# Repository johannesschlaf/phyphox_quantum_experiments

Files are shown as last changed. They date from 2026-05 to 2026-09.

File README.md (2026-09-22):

# Quantum experiments with phyphox
Language: **English** | [Deutsch](./README.de.md)

In this repository there are all the files needed for the ready-made phyphox-based quantum experiments.
 - **English instructions regarding the conduction of the experiments are now ready and available.**
 - **English instructions regarding the manufacturing of the DIY setup for measuring Planck's constant are currently in the works. They will be available in the future.**

## Measuring Planck's constant
In this experiment, the threshold voltages of LEDs with different peak wavelengths $\lambda$ are measured. From these, the respective photon energy can be calculated and plotted over $\nu=\frac{c}{\lambda}$. Planck's constant equals the slope of the line of best fit through these data pairs.<br>
This experiments needs a DIY setup that needs to be manufactured. Important manufacturing techniques include 3D printing, through-hole soldering of electronic components on a board, as well as sealing-in threaded inserts. In the folder _Instructions_ you will find a detailed construction manual.

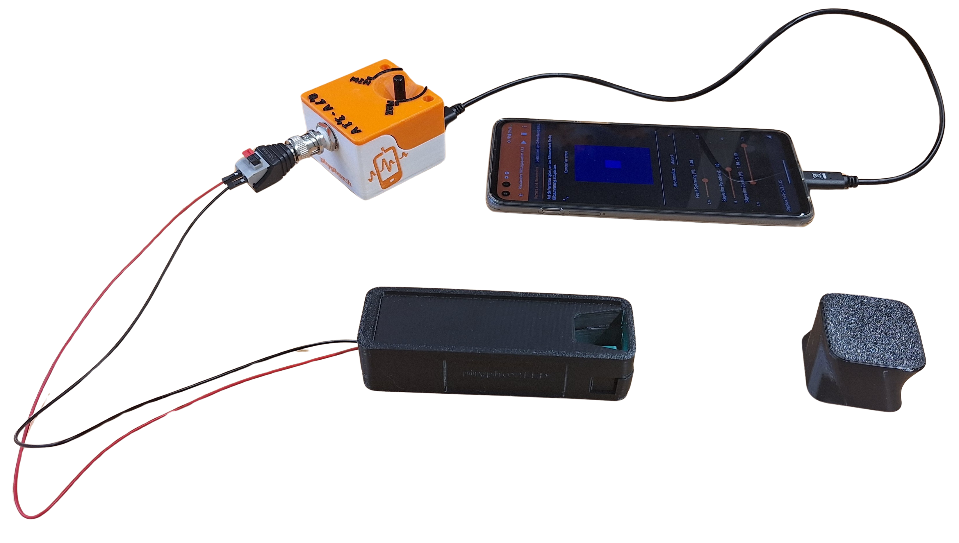
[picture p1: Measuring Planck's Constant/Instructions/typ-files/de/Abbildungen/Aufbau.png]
Picture of DIY setup
 

## BB84 analogy
The BB84 protocol is a procedure used in quantum cryptography, in which single photons in specific polarisation states are sent and measured in a specific way in order to securely generate and transmit keys simultaneously. Further information can be found in the guide in the folder _Instructions_.<br>
The basic experiment requires just two smartphones, the simulation fo an eavesdropping attempt requires three smartphones.

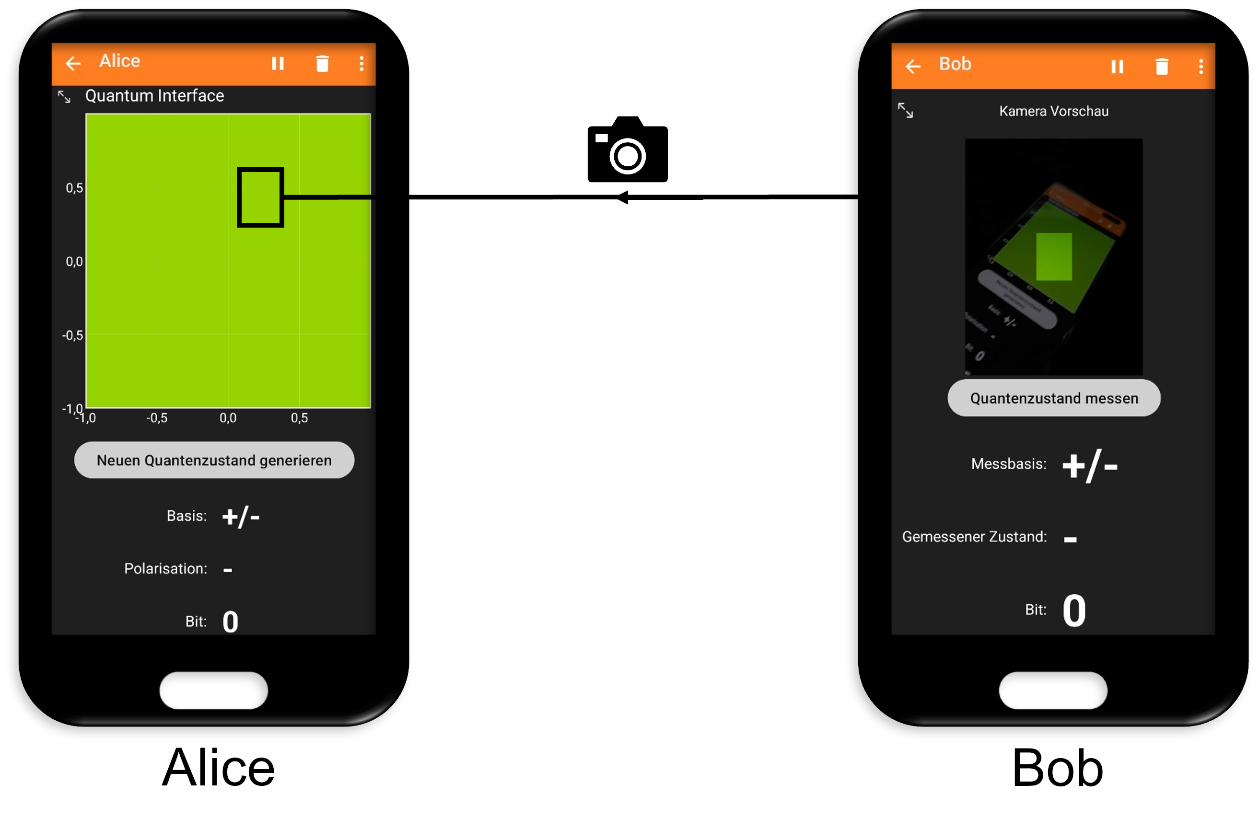
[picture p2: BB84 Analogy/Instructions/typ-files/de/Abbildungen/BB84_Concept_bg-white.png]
BB84 Concept Diagram


## Quantized conductance
...coming soon...

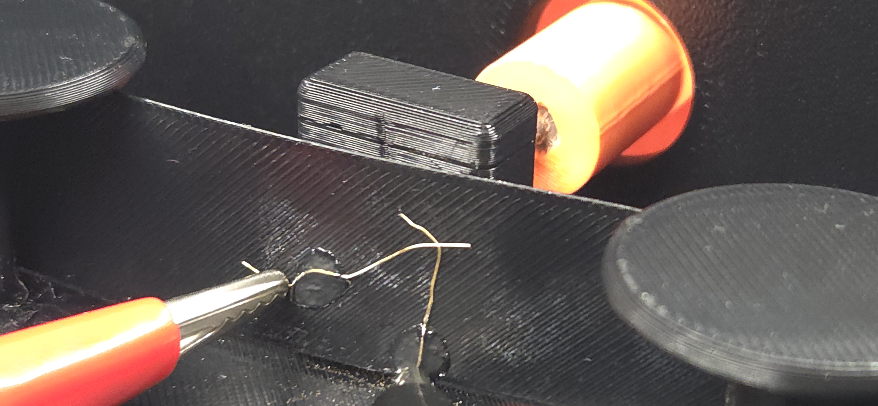
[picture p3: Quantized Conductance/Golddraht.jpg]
Picture of experimental setup


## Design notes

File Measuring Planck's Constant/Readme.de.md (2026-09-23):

# Bestimmung des Planck'schen Wirkungsquantums
Sprache: [English](./README.md) | **Deutsch**

In diesem Experiment werden die Schwellenspannungen von LEDs unterschiedlicher Peak-Wellenlängen $\lambda$ bestimmt. Aus diesen wiederum kann die zugehörige Photonenenergie berechnet und über $\nu=\frac{c}{\lambda}$ aufgetragen werden. Das Planck'sche Wirkungsquantum wird als Steigung der Ausgleichsgerade durch die aufgetragenen Punkte bestimmt.<br>
Für dieses Experiment muss ein DIY-Aufbau gefertigt werden. Wesentliche Fertigungsschritte sind 3D-Druck von Bauteilen, Durchstecklöten elektronischer Komponenten auf einer Platine sowie das Einschmelzen von Gewindeeinsätzen. 
Eine detaillierte Bauanleitung sowie eine Anleitung zur Durchführung finden sich im Ordner _Instructions_.

<br><br>
<i>
Vielen Dank an:
- Pierre Kellermann für das Konzipieren eines Prototypen der Abdunklungsbox sowie für die Stabilisierungshilfe.
- Marius Rieck für das Konzipieren eines DIY-Workshops für Schüler:innen sowie das Bereitsstellen der entsprechenden Präsentationsfolien.
</i>

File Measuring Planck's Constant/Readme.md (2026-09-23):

# Measuring Planck's Constant
Language: **English** | [Deutsch](./README.de.md)

In this experiment, the threshold voltages of LEDs with different peak wavelengths $\lambda$ are measured. From these, the respective photon energy can be calculated and plotted over $\nu=\frac{c}{\lambda}$. Planck's constant equals the slope of the line of best fit through these data pairs.<br>
This experiment needs a DIY setup that needs to be manufactured. Important manufacturing techniques include 3D printing, through-hole soldering of electronic components on a board, as well as sealing-in threaded inserts. In the folder _Instructions_ you will find a detailed construction manual.

<br><br>
<i>
Thanks to:
- Pierre Kellermann for designing a prototype for the blackout box as well as the stabilisation aid.
- Marius Rieck for creating and testing a DIY workshop concept for pupils and providing the respective presentation slides.
</i>

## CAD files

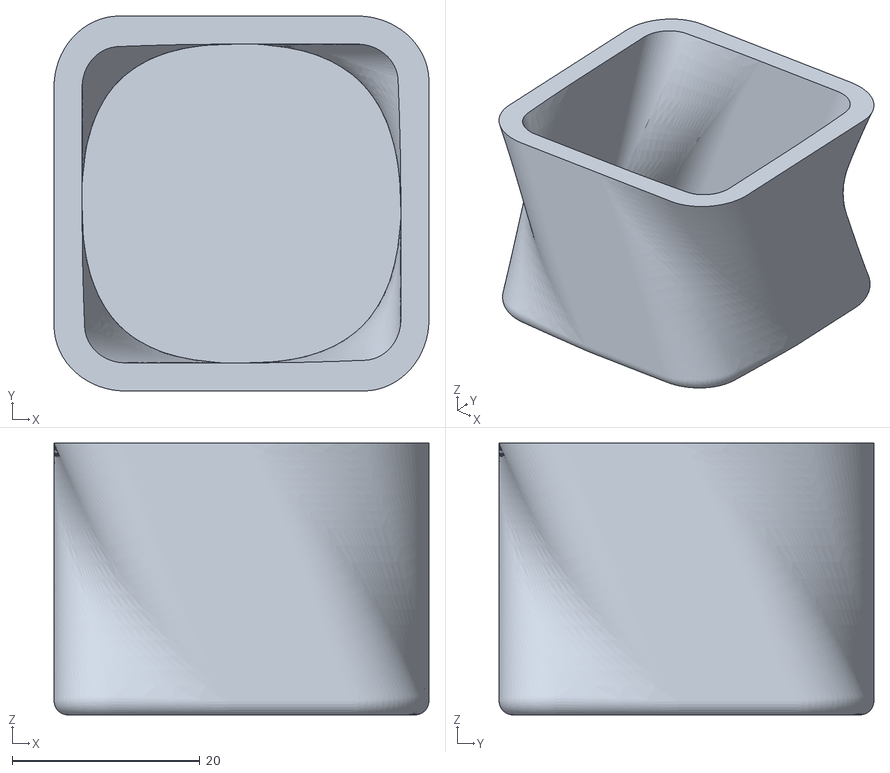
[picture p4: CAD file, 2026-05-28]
Measuring Planck's Constant/Printing files/Stabilisation_Aid_PBK.stl
40.0 x 40.0 x 29.0

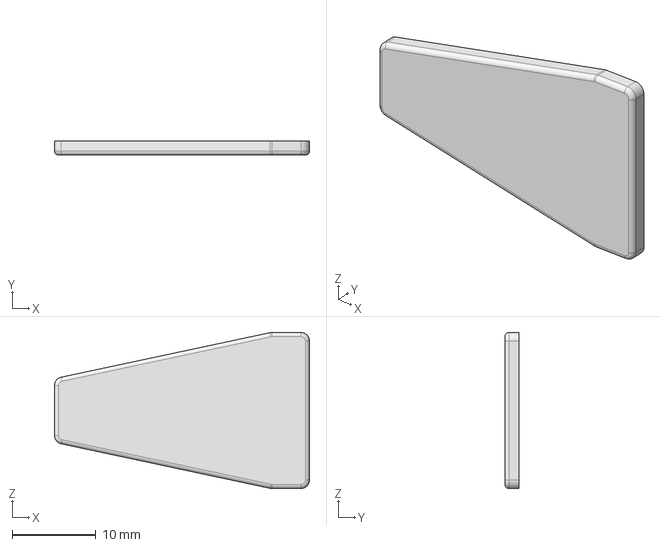
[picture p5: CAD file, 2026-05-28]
Measuring Planck's Constant/Printing files/phyphox_LED_Reflective_Insert_V3.1E.stp
30.4 x 1.70 x 18.6 mm

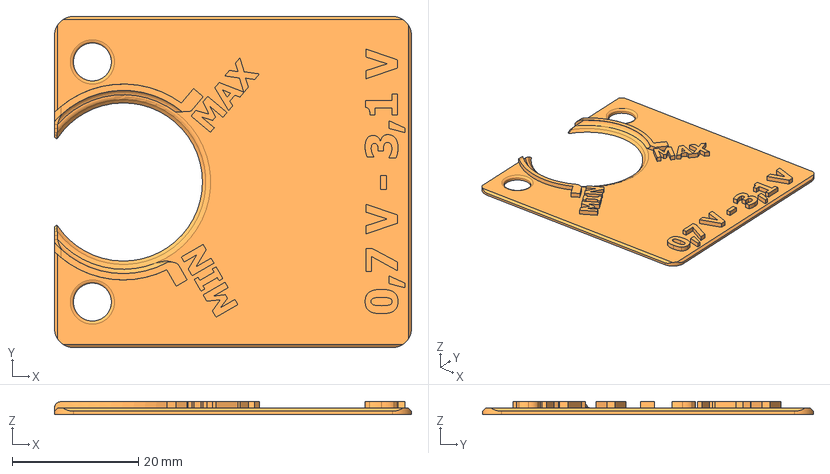
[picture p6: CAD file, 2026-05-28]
Measuring Planck's Constant/Printing files/phyphox_h_Scale_V4.2.stp
56.5 x 52.4 x 2.00 mm

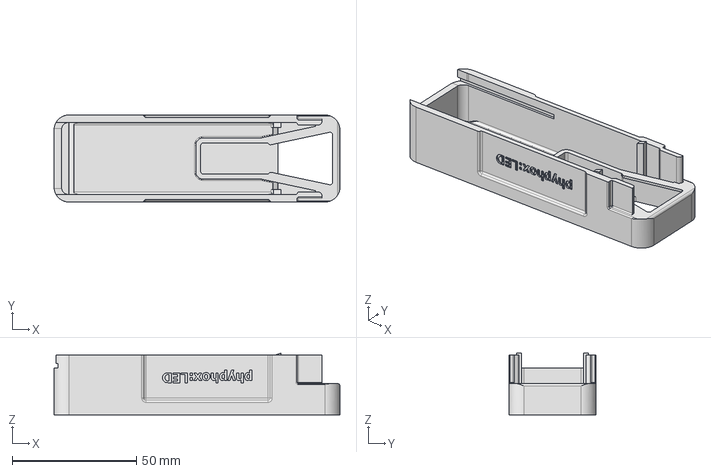
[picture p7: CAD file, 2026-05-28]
Measuring Planck's Constant/Printing files/phyphox_LED_Top_V3.5.4.stp
115.0 x 35.0 x 24.8 mm

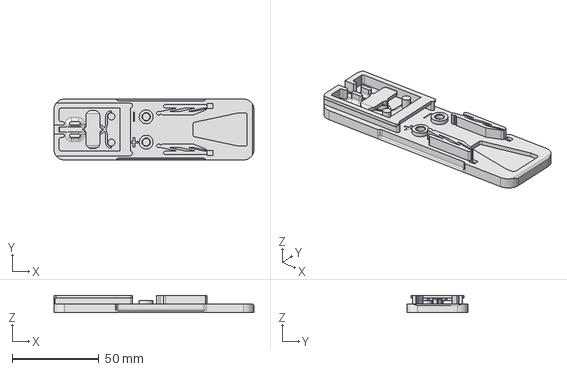
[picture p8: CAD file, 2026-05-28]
Measuring Planck's Constant/Printing files/phyphox_LED_Bottom_V3.5.3.stp
115.0 x 35.0 x 10.0 mm

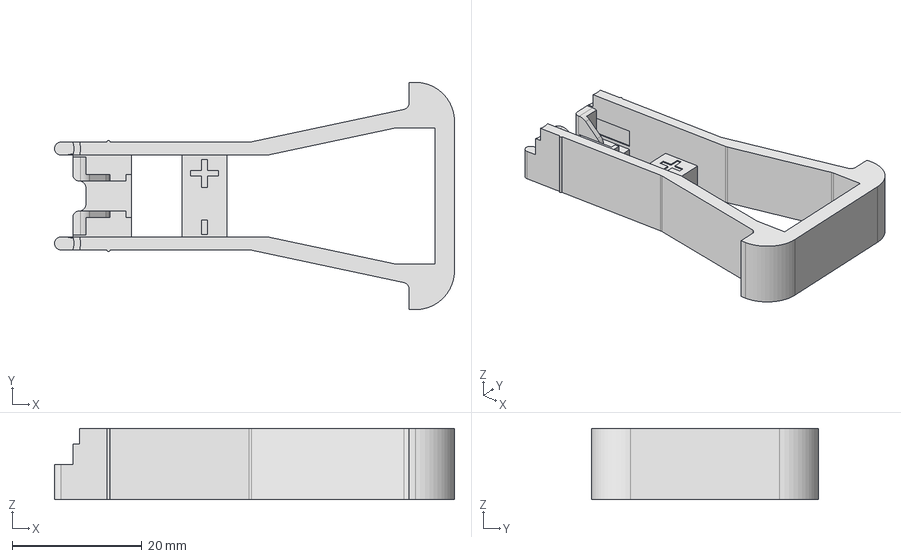
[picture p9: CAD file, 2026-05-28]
Measuring Planck's Constant/Printing files/phyphox_LED_Inset_V3.3.stp
61.6 x 35.0 x 11.0 mm

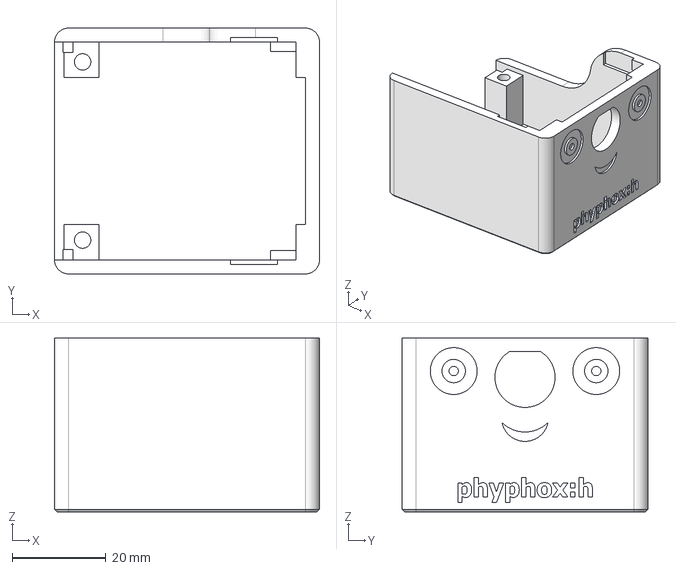
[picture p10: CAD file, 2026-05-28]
Measuring Planck's Constant/Printing files/phyphox_h_Bottom_V4.2.3.stp
56.5 x 52.4 x 37.0 mm

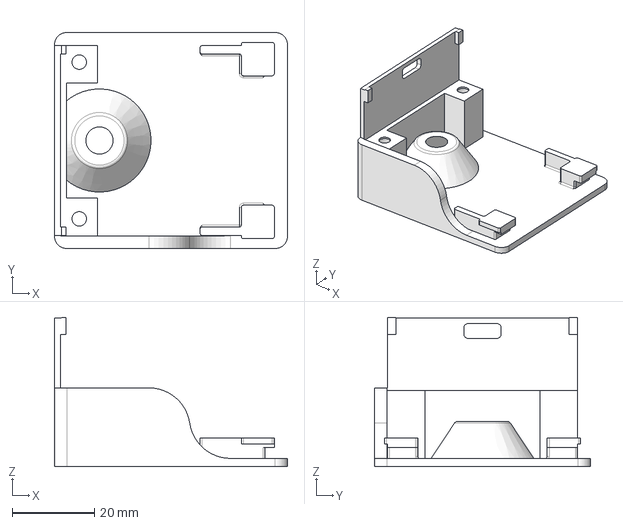
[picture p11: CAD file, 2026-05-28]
Measuring Planck's Constant/Printing files/phyphox_h_Top_V4.2.1.stp
56.5 x 52.4 x 36.2 mm

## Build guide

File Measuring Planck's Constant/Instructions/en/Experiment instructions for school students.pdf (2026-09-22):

®

# Planck’s Constant

## Material

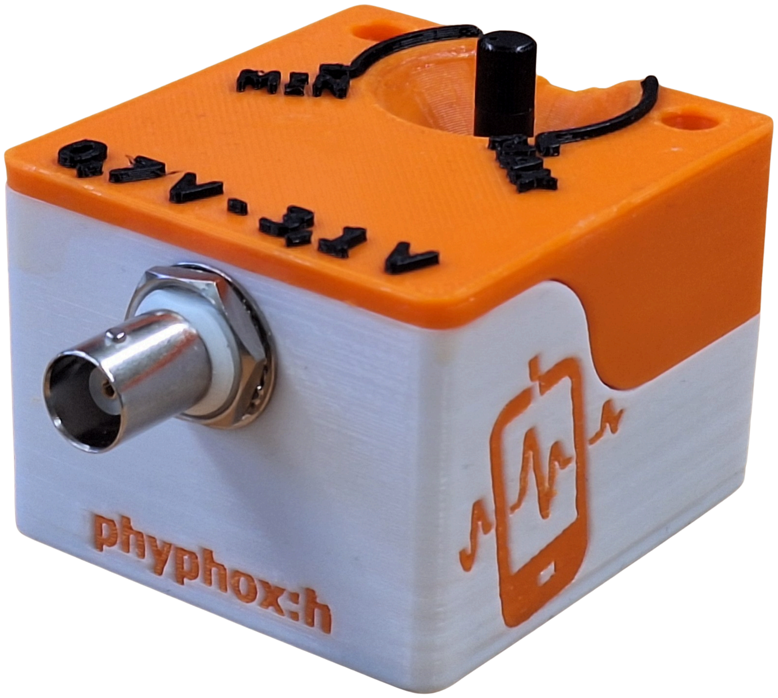
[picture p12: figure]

phyphox:h-box (voltage
control)

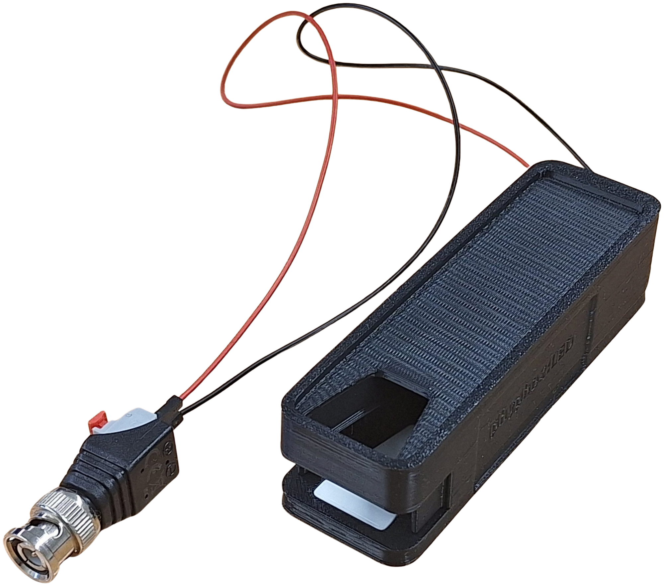
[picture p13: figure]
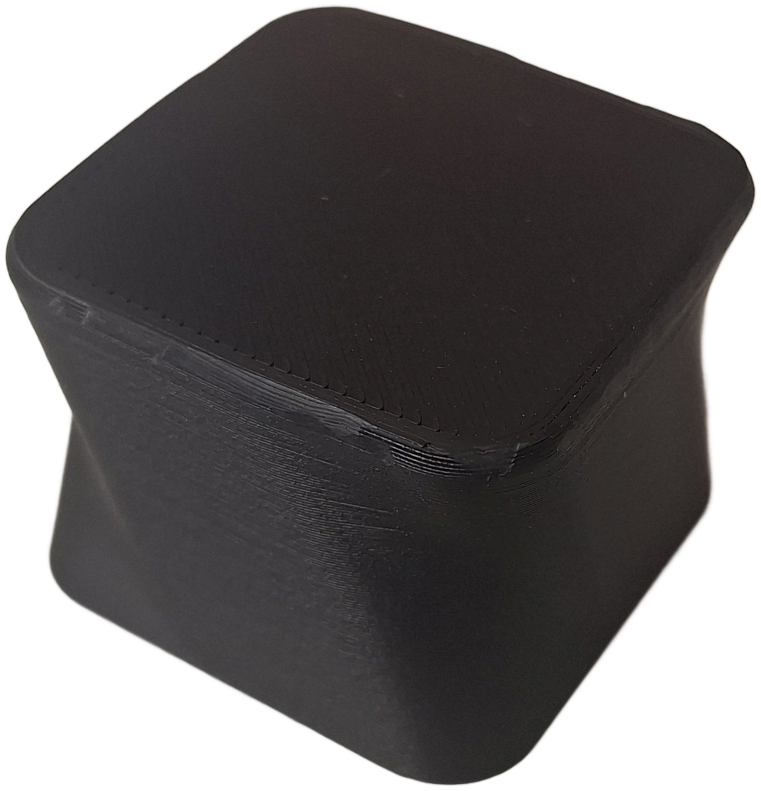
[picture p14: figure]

Blackout box | Stabilisation aid

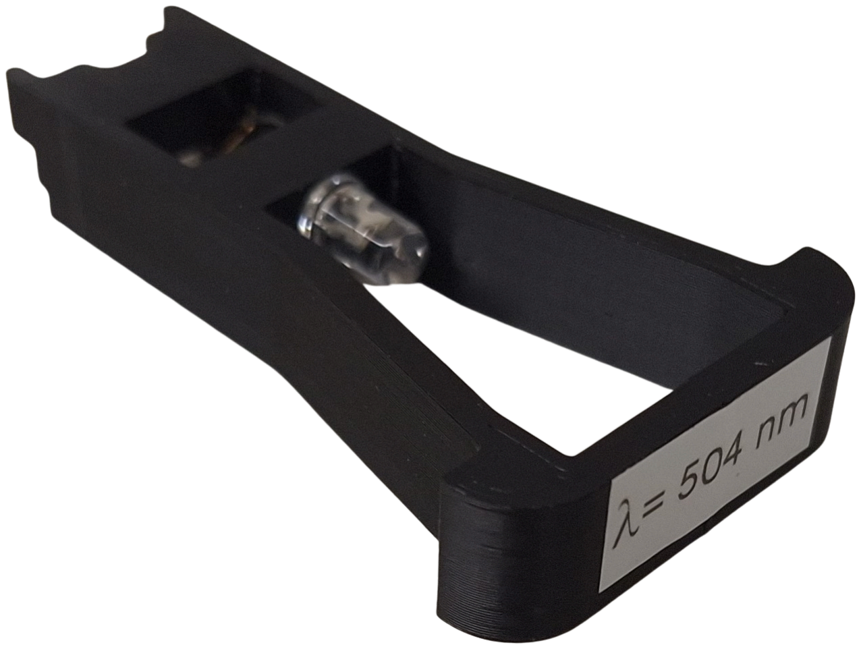
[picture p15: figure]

Various LED inserts of different wavelengths

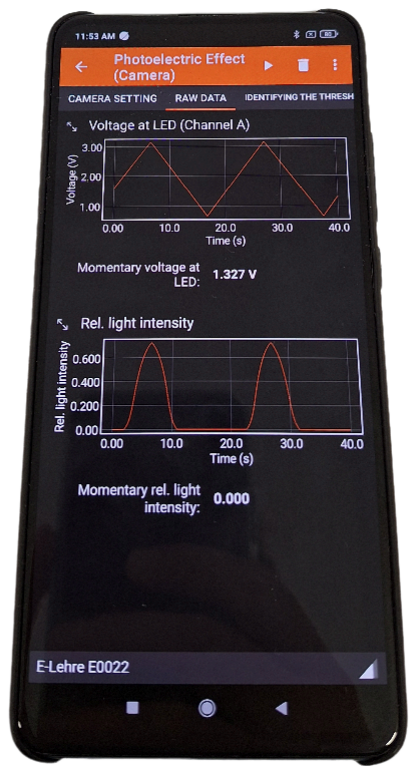
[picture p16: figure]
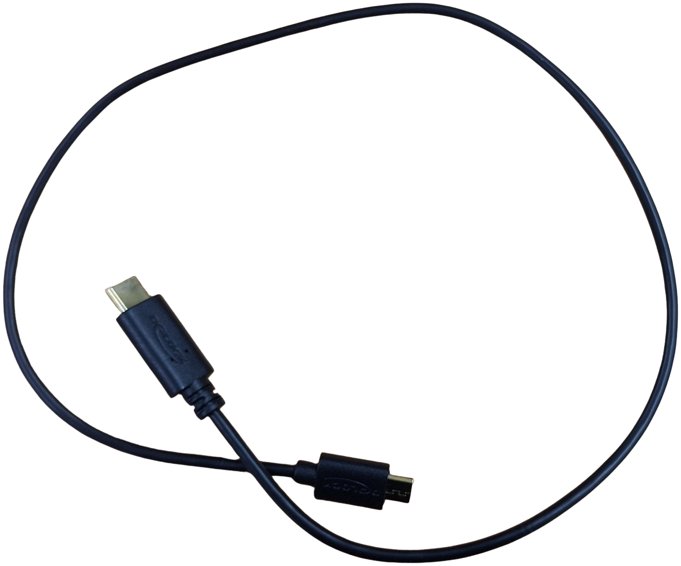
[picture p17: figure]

Connection cable | Smartphone (light intensity measurement)

This document is licensed under CC BY 4.0. https://creativecommons.org/licenses/by/4.0/. Author: Johannes Schlaf

## Setup/Preparation

1. Set up the experimental apparatus according to the figure below.
2. Download the corresponding phyphox experiment bundle:
- The phyphox: h-Box must be connected to the smartphone (or another power source).
- Open the phyphox app.
- Click on the plus symbol.
- Select „Add experiment for Bluetooth device“.
- Select your phyphox:h-Box from the list (numbering on the side).
- Wait until the download is complete.
- Save the desired experiment (or both) in the collection.

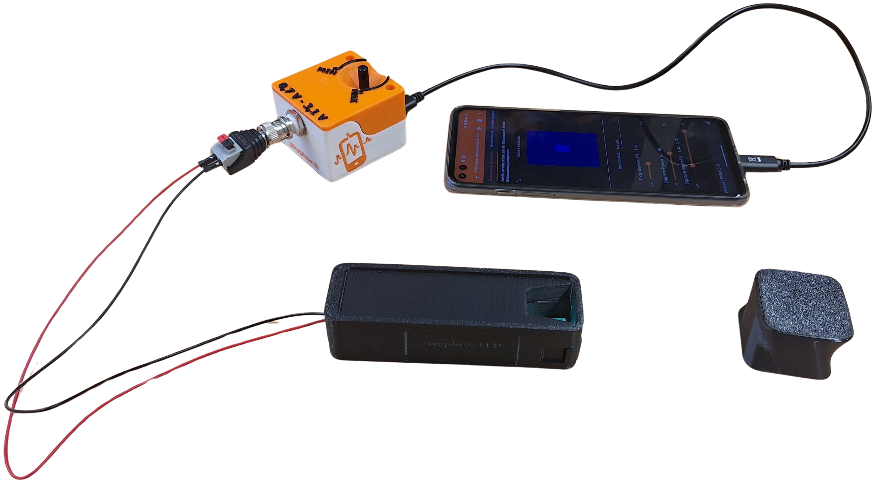
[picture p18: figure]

Completed setup

## Procedure with the smartphone camera

- If the appropriate phyphox experiment does not open automatically or needs to be reopened during the experiment:
1. Select the phyphox experiment Planck’s Constant (camera in the icon) under the Quantum Physics section.
2. Select your phyphox: h-Box from the appearing list of Bluetooth devices (the number is on the side of the box). ⇒ The box will now connect to the app and send the value of the applied voltage.
- Determine the threshold voltages of several LEDs (13 steps):
1. Insert an LED insert into the blackout box.
2. Set the voltage regulator on the phyphox: h-Box to maximum.
3. Place your smartphone on the blackout box so that the camera is positioned above the white reflective material. Use the stabilization aid if necessary.
4. Reduce the voltage to the highest value at which the camera’s selection area has no overexposure anywhere (i.e. the selection area must not contain any redmarked areas).
- The selection area is the slightly brighter rectangle within the camera preview.
- Overexposure may occur outside the selection area.
- The selection area can be moved. To do this, tap on the camera preview.
5. Switch to the „Identify the threshold voltage“ tab.
6. Start the measurement (play button in the top right).
7. Record an LED characteristic curve by slowly reducing the voltage.
8. Pause the measurement.
9. Place the green regression line in the characteristic curve by adjusting the minimum and maximum considered intensity. The regression line should run through the approximately linear region of the characteristic curve. Any saturation curve should therefore not be taken into account.
10. Note down the threshold voltage Uthreshold calculated by the experiment in the table on page 7. Also note the corresponding uncertainty.

11. Enter the wavelength of the LED in the experiment and save the wavelengththreshold voltage pair in the experiment. The pair is now available in the „Measuring h“ tab.
12. Do not use the button with the trash can symbol during the procedure. This deletes all data.
Now delete the measurement curve using the button provided specifically for this purpose.
13. Repeat the measurement process with the next LED.

## Procedure without the smartphone camera

- If the appropriate phyphox experiment does not open automatically or needs to be reopened during the experiment:
1. Select the phyphox experiment Planck’s Constant (no camera in the icon) under the Quantum Physics section.
2. Select your phyphox: h-Box from the appearing list of Bluetooth devices (the number is on the side of the box). ⇒ The box will now connect to the app and send the value of the applied voltage.
- Determine the threshold voltages of several LEDs (11 steps):
1. Set the voltage regulator on the phyphox: h-Box to minimum.
2. Insert an LED insert into the blackout box.
3. Switch to the „Determine Threshold Voltage“ tab.
4. Start the measurement (play button in the top right).
5. Record an LED characteristic curve by varying the voltage.
6. Pause the measurement.
7. Place the green regression line in the characteristic curve by adjusting the minimum and maximum considered current. The regression line should run through the approximately linear region of the characteristic curve. Any saturation curve should therefore not be taken into account.
8. Note down the threshold voltage Uthreshold calculated by the experiment in the table on page 7. Also note the corresponding uncertainty.
9. Enter the wavelength of the LED in the experiment and save the wavelengththreshold voltage pair in the experiment. The pair is now available in the „Measuring h“ tab.
10. Do not use the button with the trash can symbol during the procedure. This deletes all data.
Now delete the measurement curve using the button provided specifically for this purpose.
11. Repeat the measurement process with the next LED.

## Analysis

1. Calculate the corresponding photon energies from the threshold voltages

Reminder: e = 1.602 ⋅ 10

−19 C

1. Enter the obtained frequency-energy pairs into the diagram on page 8.
2. Draw a regression line in the diagram and determine its gradient.
3. If uncertainties were addressed:
- Draw the lines of minimum and maximum slope (within the scope of the uncertainties) in the diagram.
- Calculate the uncertainty in the measured value for Planck’s constant.
4. Compare the obtained value for Planck’s constant with the value displayed in the app and discuss possible deviations.

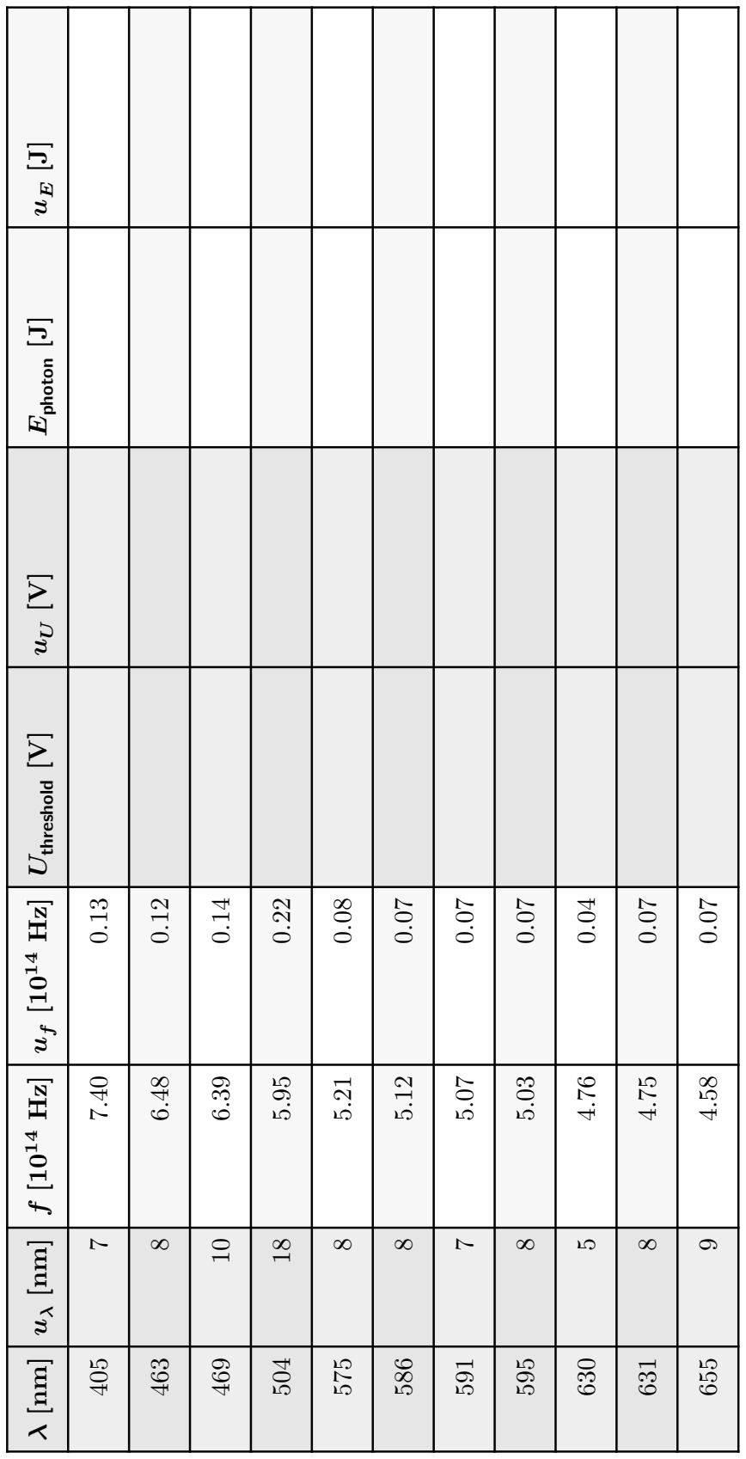
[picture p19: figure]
Uthreshold [V]; Ephoton [J]

Table 1: Measurement data of threshold voltage as a function of wavelength.

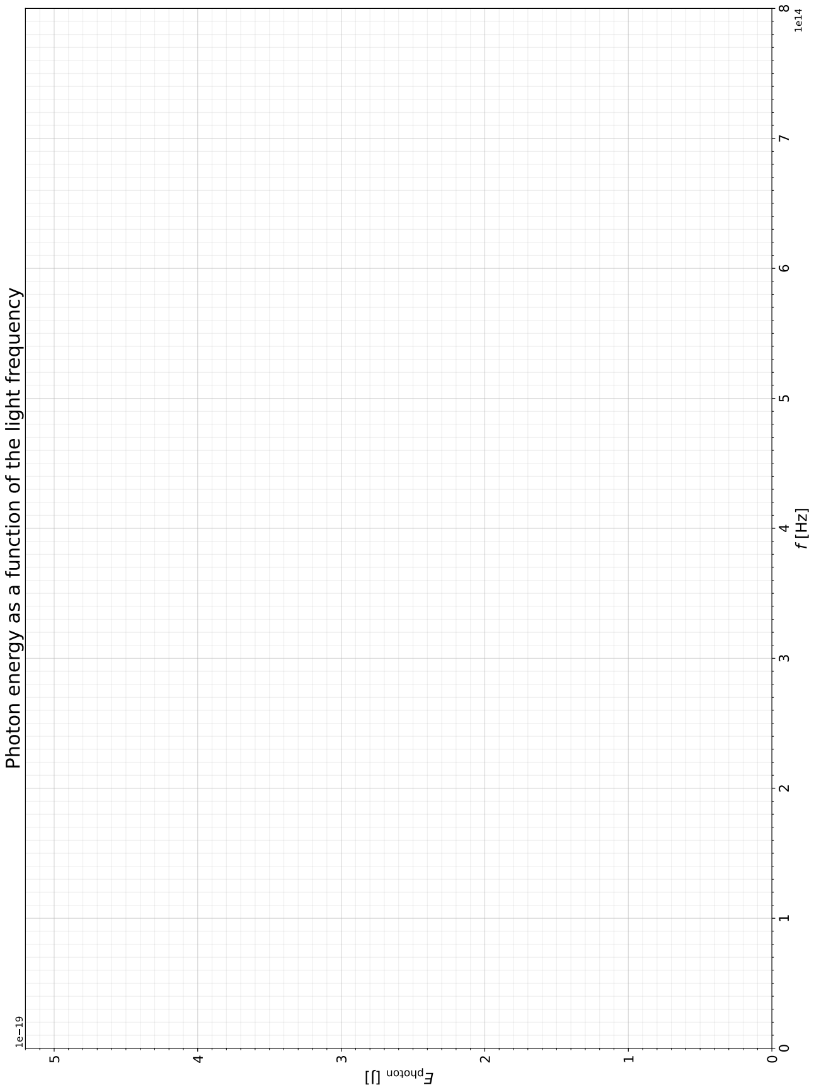
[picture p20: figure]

## 1e 19 Photon energy as a function of the light frequency



## 1e 19 Photon energy as a function of the light frequency

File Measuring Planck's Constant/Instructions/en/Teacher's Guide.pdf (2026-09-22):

®

# Planck’s Constant

## – Teacher’s Guide –

## 1 Motivation and Objective

This experiment serves to address the quantization of the energy of electromagnetic radiation, the discovery of which initiated a series of rapidly successive research studies and quantummechanical models through which numerous previously unexplained phenomena, such as emission and absorption spectra, could be explained (the introduction of Planck’s constant as a free parameter in a derivation of the black-body radiation spectrum in 1900 by Max Planck is therefore generally regarded as the birth of quantum physics, even though its interpretation as quantization of the energy of electromagnetic radiation was made later in 1905 by Albert Einstein). This is done by determining Planck’s constant from the threshold voltage of different LEDs.

## 2 Physical Foundations

### 2.1 Light

Light as an electromagnetic wave
In general, a wave is understood as a temporal change of a state that propagates through space, whereby no matter is transported but energy is. The state of an electromagnetic field is described by the electric field strength E⃗ and the magnetic induction B⃗. In an electromagnetic wave, E⃗ and B⃗ are oriented perpendicular to each other. The wave propagates in a direction that is perpendicular to the plane formed by E⃗ and B⃗. E⃗ and B⃗ change periodically (see

Figure 1).
The distance over which E⃗ and B⃗ complete one period is called the wavelength λ. It is related

to the period T and the oscillation frequency f as follows:

f =

1
T

=

c
λ

Here, c corresponds to the speed of light in vacuum (c ≈ 299,800,000 m
s

).
The perceived color of light depends on its wavelength (see Figure 2).

This document is licensed under CC BY 4.0. https://creativecommons.org/licenses/by/4.0/. Author: Johannes Schlaf

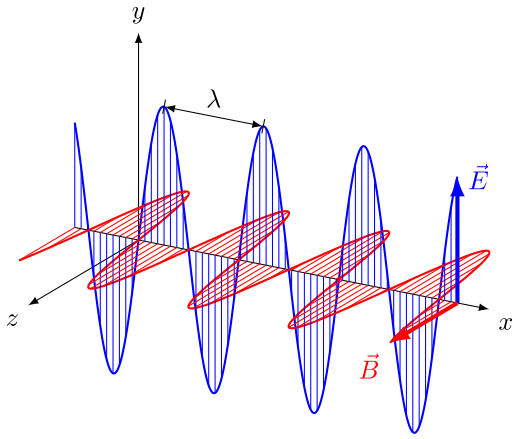
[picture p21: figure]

Figure 1: Light as an electromagnetic wave. The wavelength λ corresponds to the distance between two points of maximum electric field strength. Image source: Wikimedia Commons. By: And1mu.

Light as particles
Light energy is quantized, i.e. it exists only as multiples of the smallest possible energy units, so-called photons. The energy Eph of a photon depends on the frequency f. The following holds:

Eph = ℎ ⋅ f

The proportionality constant ℎ is called Planck’s constant. It is a fundamental physical constant.

The division of light energy into photons corresponds to the idea of very tiny light particles. It contradicts the idea of light as a continuous electromagnetic wave. Depending on the experiment, light behaves like a collection of light particles, like an electromagnetic wave, or like both simultaneously. This fact is referred to as wave-particle duality.

Figure 2: Color spectrum of visible light as a function of wavelength. Image source: Schmidt,
P. & Windhausen, S. (2024). Lohmeyer Praktische Bauphysik, p. 806. Springer Vieweg.

### 2.2 Diodes

Diodes are electronic components that conduct current only in one direction. If they are connected the wrong way round (reverse direction), they block the circuit and can be damaged if the voltage is high enough. If they are connected in the forward direction, a certain voltage, the so-called threshold voltage, must be reached before current can flow. For conventional diodes, this voltage is typically around 0.7 V. A typical current-voltage characteristic can be found in Figure 3.
The threshold voltage can be approximately determined by drawing a tangent to the characteristic curve. The threshold voltage corresponds approximately to the zero crossing of the tangent.

For so-called LEDs (Light Emitting Diodes), part of the electrical energy is converted into photons. The minimum threshold voltage Uthreshold required for the LED to emit light corresponds to the photon energy. The following holds:

EPh = e ⋅ Uthreshold

Here, e corresponds to the elementary charge (e ≈ 1.602 ⋅ 10

−19 C).

pagebreak()

## 3 Experimental Setup and Procedure

Data acquisition in this experiment is carried out with the smartphone app phyphox, developed at RWTH Aachen University. This app accesses the internal sensors of the smart-

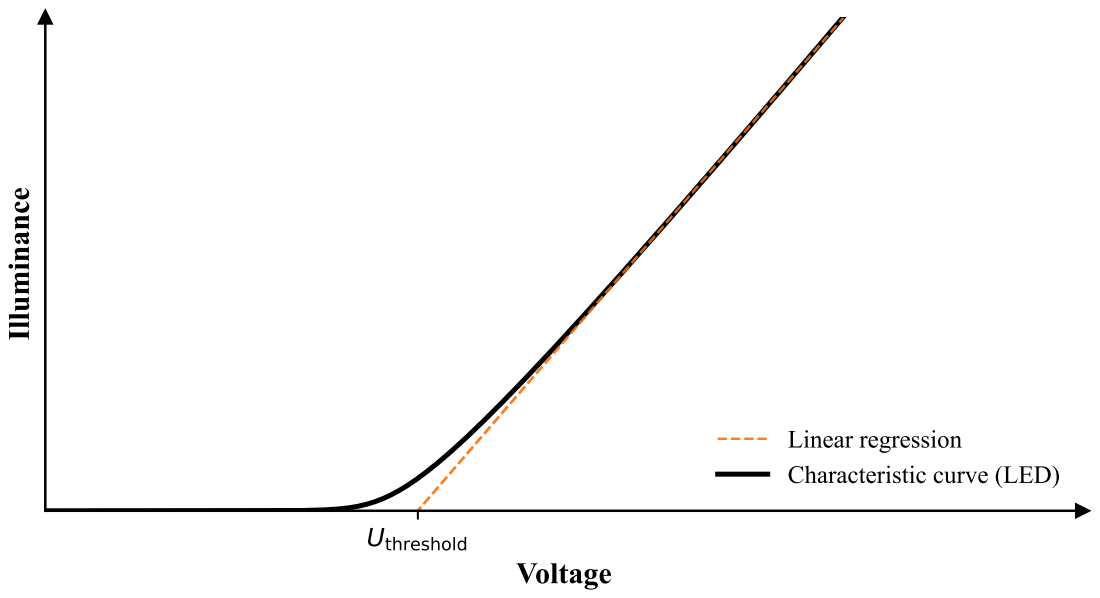
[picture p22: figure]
Uthreshold; Voltage; Illuminance; Linear regression Characteristic curve (LED)

Figure 3: Typical current–voltage characteristic of a diode with a series resistor.

phone and can thus read out measured quantities such as, for example, the instantaneous acceleration. In addition, external sensors can be integrated via Bluetooth. In phyphox, you choose what to measure by selecting one of the available experiments. New experiments can be added over Bluetooth from an external sensor device or through a QR code.

To determine the threshold voltage of an LED, a characteristic curve as in Figure 3 is required. The current through the LED is approximately proportional to its luminous intensity, so instead of measuring the current directly, you can measure the illuminance inside a blackout box. With the DIY setup provided for this experiment, both current measurement and measurement of the illuminance via the smartphone camera are possible.

Further information regarding setup, procedure, and evaluation can be found in the experiment instructions.

## 4 Background Information

- In a simplified picture, a diode consists of an n-doped semiconductor (with free electrons in the crystal lattice) and a p-doped semiconductor (with electron deficiencies / free holes) joined together. At the contact point (the so-called pn junction), a charge zone without free charge carriers forms due to the diffusion of electrons (concentration equalization) from n to p; this is the so-called depletion region. If a diode is connected with the positive terminal to n and the negative terminal to p, electrons flow from n to the positive terminal and from the negative terminal to p, which enlarges the charge zone and thus the depletion region. In this direction, only a minimal current flow in the range of a few microamperes occurs (so-called reverse current). If the LED is connected the other way round, the depletion region becomes smaller until, above a certain voltage (threshold or turn-on voltage, about 0.7 V for an ordinary diode, between 1.6 V and 3.3 V for LEDs with a visible emission spectrum), it disappears and current can flow. Photon generation occurs during the recombination of electrons (n) with holes (p), which are located at different energy levels.

Uthreshold
Voltage

Illuminance

Figure 4: Simplified characteristic curve of an LED. Current flows only after the threshold voltage is exceeded and then increases linearly with voltage.

- The simplified explanation above corresponds to the characteristic curve in Figure 4. In reality, an ideal diode actually follows the following characteristic (see Figure 5):

I = Ireverse ⋅ exp(

e ⋅ U
n ⋅ k ⋅ T

− 1)

Here, n is the so-called ideality factor or emission coefficient. For LEDs, it is typically n = 1.4.

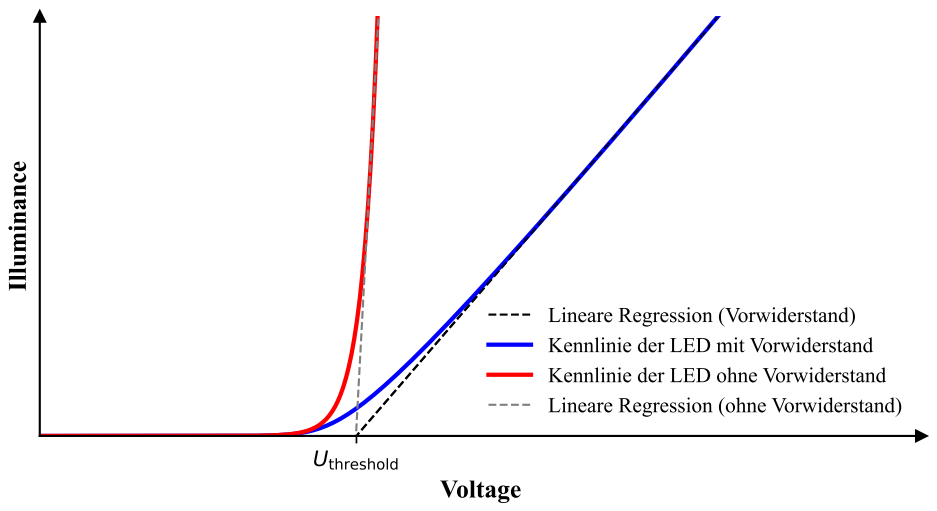
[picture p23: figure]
Uthreshold; Voltage; Illuminance; Lineare Regression (Vorwiderstand) Kennlinie der LED mit Vorwiderstand Kennlinie der LED ohne Vorwiderstand Lineare Regression (ohne Vorwiderstand)

Figure 5: Simplified characteristic curve of an LED. Current flows only after the threshold voltage is exceeded and then increases linearly with voltage.

- The threshold voltage is usually defined as the voltage at which 10 % of the maximum permissible current flows through the diode.
- Even for an ideal diode, the threshold voltage of the diode is only approximately determined by the line of best fit. This is partly because, although the characteristic curve can be approximated by a straight line locally, it follows an exponential trend overall. This is already taken into account in the phyphox experiment’s calculation of the uncertainty of the threshold voltage.
- LEDs can heat up. This leads to a change in the band structure (usually toward smaller energy differences). The LEDs should therefore not be operated for too long or with much higher voltage than necessary (operating a red LED at 3 V is generally not necessary, as the threshold voltage should be below 2 V).
- Red LEDs can have higher threshold voltages than their wavelength would suggest. This is because the energy band structure around the “light-generation zone” is often designed such that the electrons first fall to an intermediate level before recombining with the holes while emitting photons.
- If the illuminance is to be measured in the experiment:
- Overexposure of the camera must be avoided, since saturation of individual pixels (reaching the maximum brightness value in the HSV color space) in the selected area leads to distortion of the characteristic curve (see below). Therefore, the smartphone camera cannot be pointed directly at the LED, so the blackout box has a reflective surface onto which the camera should be pointed.
- The luminous intensity of an LED is only approximately proportional to the current. For higher currents, the current–luminous-intensity curve flattens, which results in a flattening of the voltage–luminous-intensity curve.
- The relative illumination values measured with the phyphox camera are not necessarily proportional to the actual illuminance everywhere.

– At higher levels, the camera often shows saturation even without overexposure, which distorts the measured curve.

– At very low illuminances, the measured values can jump abruptly.

– Some smartphone models automatically adjust the image brightness above certain light levels, so that only a scatter of points is measured.

All three effects also depend on the image processing algorithms of the respective smartphone. Turning off all switchable processing functions in the camera app can improve the measurement curves in phyphox.

- When carrying out the experiment, it is particularly important to ensure that the blackout box is sufficiently well covered and that the camera is not overexposed. Insufficient light-tightness leads to the measurement of an offset and consequently to systematically too low threshold voltages. Overexposure leads to flattening, kinks, and possibly to several approximately linear sections, which makes sensible placement of the line of best fit more difficult.

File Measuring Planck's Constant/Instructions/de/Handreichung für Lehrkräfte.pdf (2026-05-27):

®

# Das Planck’sche Wirkungsquantum

## – Handreichung für Lehrkräfte –

### 1 Motivation und Ziel

Mit diesem Versuch kann die Energiequantelung elektromagnetischer Strahlung thematisiert werden, deren Entdeckung eine Reihe schnell aufeinander folgender Forschungsarbeiten und quantenmechanischer Modelle einläutete, durch die zahlreiche vorher unverstandene Phänomene wie z.B. Emissions- und Absorptionsspektren erklärt werden konnten (die Einführung des Planck’schen Wirkungsquantums als freier Parameter in einer Herleitung zum Spektrum der Schwarzkörperstrahlung im Jahre 1900 durch Max Planck wird daher in der Regel als die Geburtsstunde der Quantenphysik bezeichnet, auch wenn dessen Deutung als Energiequantelung elektromagnetischer Strahlung erst 1905 durch Albert Einstein erfolgte). Dies erfolgt durch die Bestimmung des Wirkungsquantums aus der Schwellenspannung verschiedener LEDs.

### 2 Physikalische Grundlagen

### 2.1 Licht

Licht als elektromagnetische Welle
Unter einer Welle versteht man im Allgemeinen eine sich im Raum ausbreitende zeitliche Änderung eines Zustandes, wobei keine Materie sondern Energie transportiert wird. Der Zustand eines elektromagnetischen Feldes wird durch die elektrische Feldstärke E⃗ und die magnetische Induktion B⃗ beschrieben. Bei einer elektromagnetischen Welle sind E⃗ und B⃗ senkrecht zueinander ausgerichtet. Die Ausbreitung der Welle erfolgt in einer Richtung, die wiederum senkrecht auf der durch E⃗ und B⃗ gebildeten Ebene steht. E⃗ und B⃗ ändern sich hierbei periodisch (siehe Abbildung 1).
Die Strecke, in der E⃗ und B⃗ eine Periode durchlaufen, wird als Wellenlänge λ bezeichnet. Sie hängt mit der Periodendauer T und der Schwingungsfrequenz f wie folgt zusammen:
| f =
| 1 T = c λ

Hierbei entspricht c der Lichtgeschwindigkeit im Vakuum (c ≈ 2,988 m
| s ).
Die wahrgenommene Farbe von Licht hängt von dessen Wellenlänge ab (siehe Abbildung 2)

This document is licensed under CC BY 4.0. https://creativecommons.org/licenses/by/4.0/. Author: Johannes Schlaf

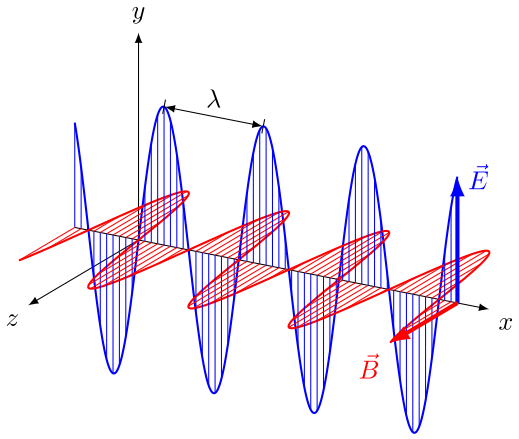
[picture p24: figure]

Abbildung 1: Licht als elektromagnetische Welle. Die Wellenlänge λ entspricht dem Abstand zweier Punkte maximaler elektrischer Feldstärke. Bildquelle: Wikimedia Commons. By: And1mu.

Licht als Teilchen
Lichtenergie ist gequantelt, d.h. sie liegt nur als Vielfaches kleinstmöglicher Energieeinheiten, sogenannter Photonen vor. Die Energie EPh eines Photons ist von der Frequenz f abhängig. Es gilt:

EPh = ℎ ⋅ f

Die Proportionalitätskonstante ℎ wird als das Planck’sche Wirkungsquantum bezeichnet. Sie ist eine fundamentale Naturkonstante.

Die Aufteilung der Lichtenergie in Photonen entspricht der Vorstellung kleinster Lichtteilchen. Sie widerspricht dem Bild von Licht als kontinuierliche elektromagnetische Welle. Je nach Experiment verhält sich Licht wie eine Ansammlung von Lichtteilchen, wie eine elektromagnetische Welle oder wie beides gleichzeitig. Diesen Sachverhalt bezeichnet man als Welle-Teilchen-Dualismus.

Abbildung 2: Farbspektrumg des sichtbaren Lichts in Abhängigkeit der Wellenlänge. Bildquelle: Schmidt, P. & Windhausen, S. (2024). Lohmeyer Praktische Bauphysik, S. 806. Springer Vieweg.

### 2.2 Dioden

Dioden sind elektronische Bauteile, welche nur in eine Richtung stromdurchlässig sind. Werden sie falsch herum angeschlossen (Sperrrichtung), sperren sie daher den Stromkreis und können, wenn die Spannung hoch genug ist, Schaden nehmen. Werden sie in Durchlassrichtung angeschlossen, muss eine gewisse Spannung, die sogenannte Schwellenspannung, erreicht werden, damit ein Strom fließen kann. Bei herkömmlichen Dioden liegt diese Spannung typischerweise bei etwa 0,7 V. Ein typische Strom-Spannungs-Kennlinie ist in Abbildung 3 zu finden.
Die Schwellenspannung kann näherungsweise bestimmt werden, indem eine Tangente an die Kennlinie angelegt wird. Die Schwellenspannung entspricht näherungsweise der Nullstelle der Tangente.

Bei sogenannten LEDs (Light Emitting Diodes) wird ein Teil der elektrischen Energie in Photonen umgesetzt. Die für das Leuchten der LED mindestens notwendige Schwellenspannung USchwelle entspricht hierbei der Photonenenergie. Es gilt:

EPh = e ⋅ USchwelle

Hierbei entspricht e der Elektronenladung (e ≈ 1,602 ⋅ 10

−19 C).

0,7 V

### Spannung

### Strom

Kennlinie der LED
Lineare Regression

Abbildung 3: Typische Strom-Spannungs-Kennlinie einer Diode mit vorgeschaltetem Widerstand.

### 3 Versuchsaufbau und Durchführung

Die Datenaufnahme erfolgt in diesem Versuch mit der an der RWTH Aachen entwickelten Smartphone-App phyphox. Diese greift auf die internen Sensoren des Smartphones zu und kann so Messgrößen wie z.B. die momentane Beschleunigung auslesen. Zudem können über Bluetooth externe Sensoren eingebunden werden. Die Auswahl, was gemessen werden soll, erfolgt über in phyphox auswählbare Experimente. Neue Experimente können über Bluetooth von einem anzusteuernden Gerät oder über einen QR-Code hinzugefügt werden.

Um die Schwellenspannung einer LED zu bestimmen, wird eine Kennlinie wie in Abbildung 3 benötigt. Der durch die LED fließende Strom ist näherungsweise proportional zu der Leuchtdichte der LED, weswegen anstelle des Stroms auch die Beleuchtungsstärke in einer Abdunklungsbox gemessen werden kann. Mit dem für dieses Experiment vorgesehenen DIY-Aufbau ist sowohl die Strommessung als auch die Messung der Beleuchtungsstärke über die Smartphone-Kamera möglich.

Weitere Informationen zu Aufbau, Durchführung und Auswertung finden Sie in der Versuchsanleitung.

### 4 Hintergrundwissen

- Eine Diode besteht (vereinfacht) aus einem n-dotierten (freie Elektronen im Kristallgitter) und einem p-dotierten (Elektronenmangen / freie Löcher) Halbleiter, die miteinander verbunden werden. Um die Kontaktstelle (den sogenannten pn-Übergang) bildet sich durch die Diffusion von Elektronen (Konzentrationsausgleich) von n zu p eine Ladungszone ohne freie Ladungsträger aus, die sogenannte Sperrschicht. Wird eine Diode mit dem Pluspol an n und dem Minuspol an p beschaltet, fließen Elektronen aus n zum Pluspol und aus dem Minuspol zu p, was die Ladungszone und somit die Sperrschicht vergrößert. In dieser Richtung kommt es nur zu einem minimalen Stromfluss im Bereich einiger Mikorampere (sogenannter Sperrstrom). Wird die LED anders herum geschaltet, verkleinert sich die Sperrschicht, bis sie ab einer bestimmten Spannung (Schwellen- oder Schleusenspannung, etwas 0,7 V für eine gewöhnliche Diode, zwischen 1,6 V und 3,3 V für LEDs mit sichtbarem Emissionsspektrum) verschwindet und ein Strom fließen kann. Die Photonenerzeugung erfolgt bei der Rekombination der Elektronen (n) mit den Löchern (p), welche sich auf unterschiedlichen Energieniveaus befinden.

0,7 V
Spannung

Strom

Abbildung 4: Vereinfachte Kennlinie einer LED. Es fließt erst ab dem Überschreiten der Schwellenspannung ein Strom, der linear zur Spannung verläuft.

- Der vereinfachten Erklärung oben entspricht die Kennlinie in Abbildung 4. Tatsächlich folgt auch eine ideale Diode der folgenden Kennlinie (siehe auch Abbildung 5):

I = ISperr ⋅ exp(

e ⋅ U
n ⋅ k ⋅ T

− 1)

Hierbei ist n der sogenannte Idealitätsfaktor oder Emissionskoeffizient. Für LEDs liegt er üblicherweise bei n = 1,4.

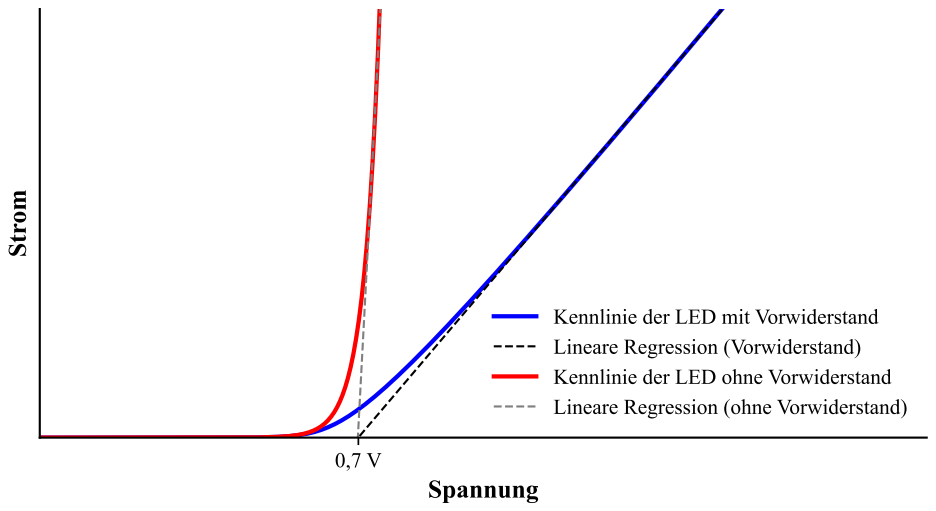
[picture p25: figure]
Spannung; Strom; Kennlinie der LED mit Vorwiderstand Lineare Regression (Vorwiderstand) Kennlinie der LED ohne Vorwiderstand Lineare Regression (ohne Vorwiderstand)

Abbildung 5: Vereinfachte Kennlinie einer LED. Es fließt erst ab dem Überschreiten der Schwellenspannung ein Strom, der linear zur Spannung verläuft.

- Die Schwellenspannung wird üblicherweise definiert als die Spannung, bei der 10 % des maximal zulässigen Stroms durch die Diode fließen.
- Selbst für eine ideale Diode wird die Schwellenspannung der Diode nur näherungsweise durch die Ausgleichsgerade bestimmt. Dies liegt unter anderem daran, dass die Kennlinie sich lokal zwar durch eine Ausgleichsgerade annähern lässt, global jedoch einem exponentiellen Verlauf folgt. Dies wird im phyphox-Experiment in der Berechnung der Unsicherheit auf die Schwellenspannung bereits berücksichtigt.
- LEDs können sich erhitzen. Dies führt zu einer Änderung der Bandstruktur (i.d.R. hin zu kleineren Energiedifferenzen). Die LEDs sollten daher nicht zur lange oder mit sehr viel höherer Spannung als notwendig betrieben werden (eine rote LED mit 3 V zu betreiben ist i.d.R. nicht notwendig, da die Schwellenspannung bei unter 2 V liegen sollte).
- Rote LEDs können höhere Schwellenspannungen haben, als es ihre Wellenlänge vermuten lassen würde. Dies liegt daran, dass die Energiebandstruktur um die „Lichterzeugungszone“ häufig so gestaltet ist, dass die Elektronen zunächst auf ein Zwischenniveau fallen, bevor sie unter Photonenabgabe mit den Löchern rekombinieren.
- Falls im Versuch die Beleuchtungsstärke gemessen werden soll:
- Eine Überbelichtung der Kamera ist zu vermeiden, da das Sättigen einzelner Pixel (Erreichen des maximalen Helligkeitswerts im HSV-Farbraum) im Auswahlbereich zur Verfälschung der Kennlinie (siehe weiter unten) führt. Daher kann die Smartphone-Kamera auch nicht direkt auf die LED gerichtet werden. Stattdessen kommt ein Reflexionsmaterial in der Abdunklungsbox zum Einsatz, auf welches die Kamera gerichtet wird.
- Die Leuchtdichte einer LED ist nur näherungsweise proportional zum Strom. Für höhere Ströme flacht die Strom-Leuchtdichten-Kurve ab, was sich in einer Verringerung der Steigung der Spannungs-Leuchtdichten-Kennlinie niederschlägt.
- Die mit der phyphox-Kamera gemessenen relativen Beleuchtungswerte sind nicht notwendigerweise überall proportional zur tatsächlichen Beleuchtungsstärke.

– Im höheren Wertebereich zeigt sich auch ohne Überbelichtung häufig ein Sättigungsverlauf, der sich in der Kennlinie niederschlagen kann.

– Bei sehr geringen Beleuchtungsstärken kann es zu sprunghaften Anstiegen kommen.

– Ab einer gewissen Beleuchtungsstärke kommt es bei einigen Smartphone-Modellen zu einem Gegenregeln der Bildhelligkeit, sodass nur noch eine Punktewolke gemessen wird.

Alle drei Effekte sind unter anderem auch von den Bildprozessierungsalgorithmen des jeweiligen Smartphones abhängig. Ein Ausschalten aller ausschaltbaren Prozessierungsfunktionen in der Kamera-App kann die Messkurven in phyphox verbessern.

- Bei der Durchführung ist vor allem darauf zu achten, dass die Abdunklungsbox hinreichend gut abgedeckt ist und dass die Kamera nicht überbelichtet. Eine unzureichende Abdunklung führt zur Messung eines Offsets und folglich zur Messung systematisch zu geringer Schwellenspannungen. Eine Überbelichtung führt zu Abflachungen, Knicken und ggf. zu mehreren näherungsweise linearen Abschnitten, was eine sinnvolle Platzierung der Ausgleichsgeraden erschwert.

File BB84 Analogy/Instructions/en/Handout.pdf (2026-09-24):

®

# The BB84 protocol

## – Handout for the analogy experiment –

## 1 Background and Theory

The BB84 protocol is a method from quantum cryptography. It provides a way to generate digital keys by exploiting quantum effects and to exchange them in a manner that is secure against eavesdropping. It was published in 1984 by Charles H. Bennett and Gilles Brassard.

### 1.1 Motivation

Many common encryption algorithms can be cracked significantly faster by sufficiently powerful quantum computers than by classical computers. One example is the RSA scheme, where security is based on the difficulty of factoring sufficiently large numbers (prime factors with over 100 digits) in a reasonable time (this currently takes several weeks). The so-called Shor algorithm, which was already published in 1994, was designed for sufficiently large and low-error quantum computers, and could perform such a factorisation in a reasonable time (presumably a few seconds). For this reason, it is sensible to study quantum-cryptographic protocols in which security arises from exploiting specific quantum effects that cannot be beaten by greater computational power and/or quantum computing.

### 1.2 Concept of message transmission

To transmit messages securely, a key is required. In message transmission, every message and every key consists of zeros and ones. Encryption can be performed according to the following rules:

0 + 0 = 1 | 0 + 1 = 1 + 0 = 1 | 1 + 1 = 0

ℎ

v

ℎ/v measuring base

− | +

+/− measuring base

Figure 1: Four polarisation states, divided into two measurement bases.

This document is licensed under CC BY 4.0. https://creativecommons.org/licenses/by/4.0/. Author: Johannes Schlaf

This could look as follows:

Message: | 1 1 0 0 0 1 1 1 0
Key: | 0 1 1 0 1 0 0 0 1
Encrypted Message: | 1 0 1 0 1 1 1 1 1

Since both 0 + 0 = 0 and 1 + 1 = 0 hold, the key can also be used again for decryption:

Encrypted Message: | 1 0 1 0 1 1 1 1 1
Key: | 0 1 1 0 1 0 0 0 1
Message: | 1 1 0 0 0 1 1 1 0

Since keys are generally at least as long as the message (and thus the key does not repeat within the message), it is not possible to decrypt the encrypted message without knowing the key. To ensure secure transmission, one therefore “only” needs to exchange the key in a manner that is secure against eavesdropping. The BB84 protocol can be used for this purpose.

### 1.3 Physical Foundations of the BB84 Protocol

In the BB84 protocol, single photons are sent from a sender (usually called Alice) to a receiver (usually called Bob). The following properties of single photons are crucial for the protocol to work:

- A single photon cannot be copied.
⇒ One can measure the polarisation state of a single photon only once.
- A single photon cannot be split.

The latter property ensures that the polarisation state can only be measured sharply if the photon can assume only one of two known, mutually orthogonal states.

Example: If I know that a photon is polarised either in the ℎ or in the v direction (see Figure 1), I can align a polariser in the v direction. A v-polarised photon then passes through with 100% probability, but an ℎ-polarised photon will not pass through. This way the state is measured sharply. However, if a photon that is neither ℎ- nor v-polarised passes through the polariser, it cannot split into a v component and an ℎ component, so it passes through with a probability that depends on the angle relative to the v direction. Since this this probability is unknown, I cannot make a statement about the polarisation state (except “not ℎ” if the photon passes through, and “not v” if it does not).

The above example holds for all pairs of mutually orthogonal states. Such a pair of states is therefore also called a measurement basis. In the BB84 protocol, two measurement bases rotated by 45° with respect to each other are used (see Figure 1).

### 1.4 Procedure of the BB84 Protocol

1. Alice sends a random sequence of polarisation states to Bob.
2. Bob knows that each single photon was prepared either in the ℎ/v measurement basis or in the +/− measurement basis. Therefore, he measures each single photon randomly either in the ℎ/v basis or in the +/− basis:
- Suppose Alice sends an ℎ-polarised photon.
- If Bob measures the photon in the ℎ/v basis, he will also measure an ℎ polarisation.
- If Bob measures the photon in the +/− basis, he can only measure a + or a − polarisation. Since the ℎ/v and +/− measurement bases are rotated by 45° with respect to each other, Bob measures a + polarisation with a probability of 50% and a − polarisation with a probability of 50% as well.
3. For each transmitted photon, Alice and Bob compare the chosen basis system. For those single photons where the basis systems agree, Bob must have measured the polarisation state sent by Alice. Only the states of these photons are taken into account for key generation.
4. The key is generated as follows:
- ℎ polarisation or − polarisation: 0
- v polarisation or + polarisation: 1
5. Alice compares the first few digits of the key she generated with the first few digits of the key Bob generated (in reality about 1000 digits) to ensure that the transmission has worked.

An example can be found in Figure 2.

### 1.5 Further Explanations

1. The comparison of the measurement bases can be carried out over a channel that is not secure against eavesdropping. The only information conveyed this way is for

## Alice

## Bob

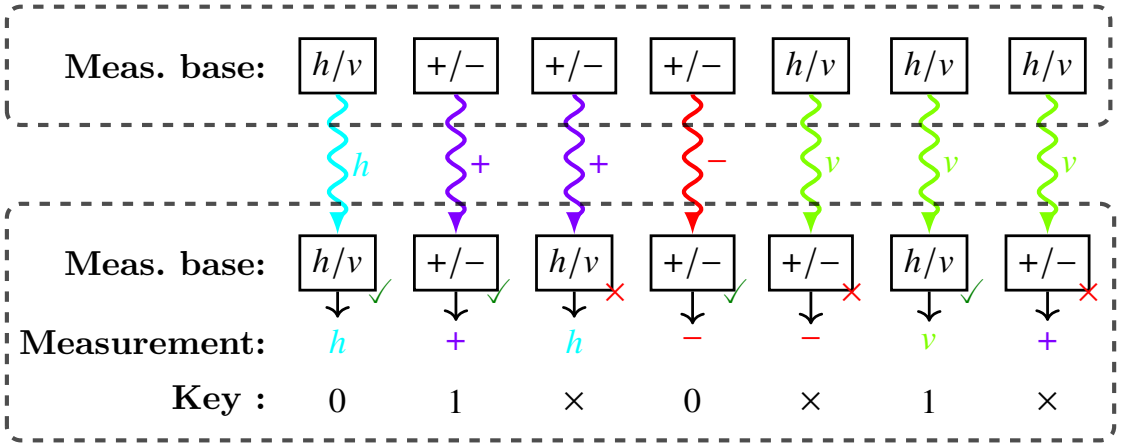
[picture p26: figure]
Meas. base:; Measurement: Key :

Figure 2: Example of the BB84 protocol.

which measurements Bob chose the correct measurement basis. The measured states themselves, and thereby also the key, remain known only to Alice and Bob.

2. If the key transmission is to be eavesdropped, the eavesdropper (usually referred to as Eve, from eavesdropping) would have to insert herself between Alice and Bob, since single photons cannot be copied. In order for Bob not to notice this, Eve must forward the measured polarisation states to Bob. Since Eve will choose the “wrong” measurement basis with a probability of 50%, errors occur in the transmission of the states from Alice to Bob. These become apparent when Alice and Bob compare the first few digits of the keys they generated. In this way, the eavesdropping is detected.

## 2 The Experiment

### 2.1 Overview and Preparation

Since single-photon sources are expensive and cumbersome to align, you will perform an analogy experiment in phyphox. Here, transmitted single photons are simulated by coloured patches on the smartphone screen (see Figure 3). Each polarisation state is assigned exactly one colour. To measure the state, one can use the camera of a second device to read out the colour of the patch and the associated polarisation state. This is then internally “measured.”[1]

There are a total of seven phyphox experiments for the BB84 protocol. Three of these are intended for the introductory experiments and four for the advanced experiments. The experiments can be loaded as a bundle in the phyphox app via the QR code at the top right of this page. To do this, tap the plus symbol in phyphox and select “New experiment from a QR code”.

For each of the experiments there is a table on the worksheet.

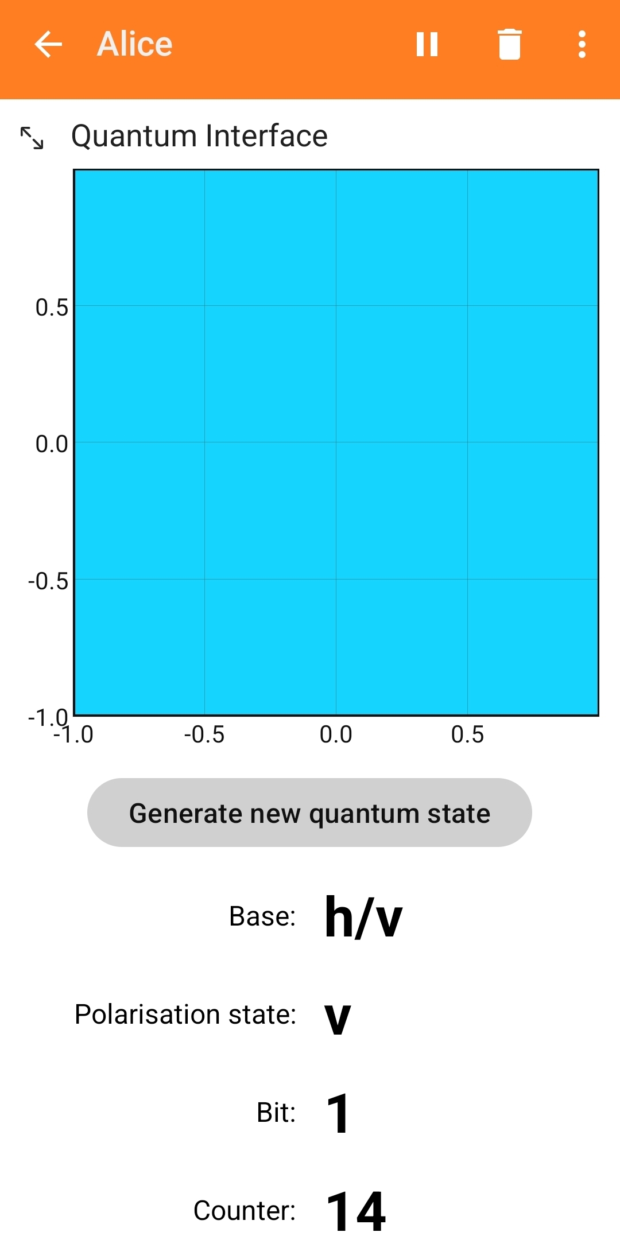
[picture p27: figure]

Figure 3: Screenshot
from phyphox.

## 3 Introductory Experiments

These experiments should definitely be carried out before the advanced experiments. The corresponding phyphox experiments are:

- Alice: Sends polarisation states (as coloured patches)
- Bob: “Measures” polarisation states by reading out Alice’s coloured patches with the camera.
- Eve: Intercepts polarisation states from Alice and forwards the measured states to Bob.

[1]Random numbers generated from the noise of the accelerometer is used to both generate and measure the states. These are overlaid with pseudo-random numbers to ensure that the experiment functions even on devices with a defective accelerometer.

Experiment 1: Key Generation
For this experiment, two people and two smartphones are required. One person operates the Alice experiment, the other person operates the Bob experiment.
Have Alice and Bob generate a key using the BB84 protocol. Use the table on the worksheet for this!

The BB84 protocol

1. Alice generates a random polarisation state.
2. Bob measures the polarisation state using a random measurement basis.
3. Alice and Bob record the basis they each chose and the polarisation state they generated / measured.
4. Alice and Bob record the bit associated with the polarisation direction: 0 for ℎ or −, 1 for v or =.
5. Alice and Bob repeat steps 1–4 several times.
6. Alice and Bob compare the measurement bases for each measurement.
7. If the measurement bases agree, the corresponding bit is used for the key (otherwise it is not).

Experiment 2: Eavesdropping
In this experiment, you should investigate what happens when a third party tries to eavesdrop on the key transmission. The Eve experiment is intended for this purpose. Eve inserts herself between Alice and Bob. She intercepts single photons from Alice and measures the polarisation states. She then forwards the measured states to Bob.
a) Carry out the BB84 protocol as before, with Eve between Alice and Bob. Use the table on the worksheet for this!
Since Alice and Bob are unaware of Eve, they continue to compare their measurement bases with each other during key generation.
b) Compare the key generated by Alice with the key generated by Bob.
- What do you notice?
- How can your observation be explained?

### 3.1 Advanced Experiments

In these experiments, a total of four phyphox experiments are used:

- V-Alice
- V-Bob
- V-Eve
- Eve, u there?

V-Alice differs from Alice in that the transmitted polarisation states are no longer directly visible. This is achieved by two measures:

1. The generated states (max. 20) are stored in a separate tab so that they can be transferred to a table at a later time.
2. The colours are no longer uniquely assigned to a polarisation state. Instead, the colour signal is encrypted using pseudo-random numbers.

V-Bob differs from Bob in that he can decrypt the colour signal again. V-Eve and Eve differ in all aspects that concern V-Alice and V-Bob.

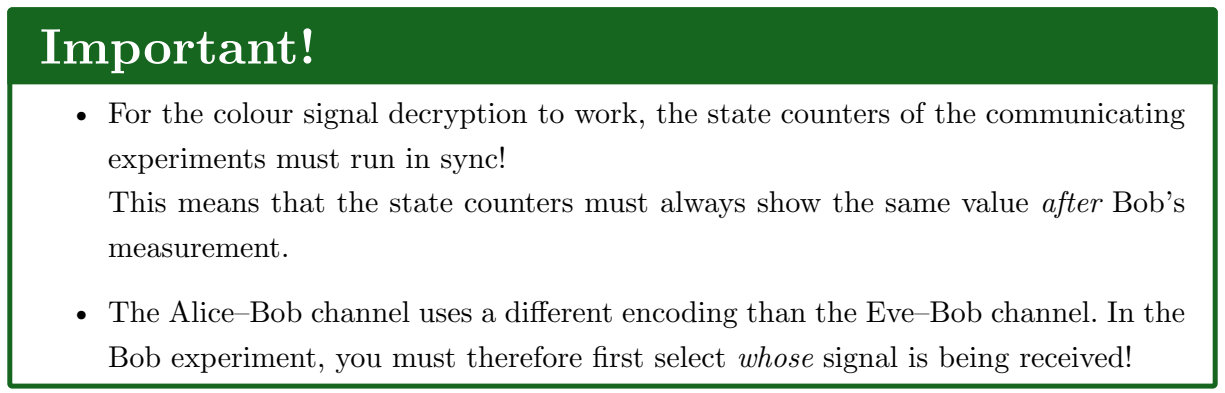
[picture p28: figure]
Important!; experiments must run in sync!; measurement.

- For the colour signal decryption to work, the state counters of the communicating

This means that the state counters must always show the same value after Bob’s

- The Alice–Bob channel uses a different encoding than the Eve–Bob channel. In the Bob experiment, you must therefore first select whose signal is being received!

The goal of making the transmitted states non-visible is to bring the analogy closer to reality. After all, during photon transmission, Alice and Bob cannot check whether the key transmission has worked as intended.

Experiment 3: Covert Key Generation This experiment corresponds to Experiment 1.

Experiment 4: Covert Eavesdropping This experiment corresponds to Experiment 2.

Experiment 5: Eve, u there?
This experiment is performed like Experiment 3, with the following change:
Instead of “V-Alice”, the experiment “Eve, u there?” is used. It works exactly like “V-Alice” (i.e. Bob sets the channel to Alice–Bob), but Eve can be activated via a separate tab, who then internally measures the generated state and outputs it as a colour signal.
For Bob, it is not apparent whether he is receiving the colour signal from Alice or from Eve. The aim of the experiment is for Bob to determine whether the key transmission has been eavesdropped on or not.

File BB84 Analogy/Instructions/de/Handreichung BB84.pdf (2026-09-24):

®

# Das BB84-Protokoll

## – Handreichung zum Analogieexperiment –

## 1 Hintergrund und Theorie

Das BB84-Protokoll ist ein Verfahren aus der Quantenkryptographie. Es stellt eine Möglichkeit dar, digitale Schlüssel durch die Nutzung von Quanteneffekten zu generieren und zugleich abhörsicher auszutauschen. Es wurde 1984 von Charles H. Bennet und Gilles Brassard vorgeschlagen.

### 1.1 Motivation

Viele gängige Verschlüsselungsalgorithmen können durch hinreichend leistungsfähige Quantencomputer essentiell schneller als durch klassische Computer geknackt werden. Ein Beispiel hierfür ist das Verfahren RSA, dessen Sicherheit auf der Unlösbarkeit einer Primfaktorzerlegung hinreichend großer Zahlen (Primfaktoren mit über 100 Stellen) in angemessener Zeit basiert (aktuell werden mindestens mehrere Wochen benötigt). Der für hinreichend große und fehlerarme Quantencomputer konzipierte und bereits 1994 veröffentlichte sogenannte Shor-Algorithmus könnte eine solche Primfaktorzerlegung in angemessener Zeit schaffen (vermutlich wenige Sekunden). Aus diesem Grund ist es sinnvoll, sich mit quantekryptographischen Verfahren auseinanderzusetzen, bei denen die Sicherheit aus der Ausnutzung bestimmter Quanteneffekte stammt, welche nicht durch eine größere Rechenleistung und/ oder Quantencomputing ausgehebelt werden können.

### 1.2 Konzept der Nachrichtenübertragung

Um Nachrichten sicher zu übertragen, wird ein Schlüssel benötigt. Jede Nachricht und jeder Schlüssel besteht in der Nachrichtenübertragung aus Nullen und Einsen. Die Verschlüsselung kann nach den folgenden Regeln erfolgen:

0 + 0 = 1 | 0 + 1 = 1 + 0 = 1 | 1 + 1 = 0

This document is licensed under CC BY 4.0. https://creativecommons.org/licenses/by/4.0/. Author: Johannes Schlaf

ℎ

v

ℎ/v-Messbasis

− | +

+/− -Messbasis

Abbildung 1: Vier Polarisationszustände, aufgeteilt auf zwei Messbasen.

Dies könnte folgendermaßen aussehen:

Nachricht: | 1 1 0 0 0 1 1 1 0
Schlüssel: | 0 1 1 0 1 0 0 0 1
Verschlüsselte Nachricht: | 1 0 1 0 1 1 1 1 1

Da sowohl 0 + 0 = 0 als auch 1 + 1 = 0 gilt, kann der Schlüssel auch wieder zum Entschlüsseln verwendet werden:

Verschlüsselte Nachricht: | 1 0 1 0 1 1 1 1 1
Schlüssel: | 0 1 1 0 1 0 0 0 1
Nachricht: | 1 1 0 0 0 1 1 1 0

Da Schlüssel in der Regel mindestens genauso lang wie die Nachricht sind (und sich somit der Schlüssel nicht innerhalb der Nachricht wiederholt), ist es nicht möglich, die verschlüsselte Nachricht zu entschlüsseln, ohne den Schlüssel zu kennen. Um eine sichere Übertragung zu gewährleisten, muss also „nur“ der Schlüssel abhörsicher ausgetauscht werden. Hierzu kann das BB84-Protokoll genutzt werden.

### 1.3 Physikalische Grundlagen des BB84-Protokolls

Beim BB84-Protokoll werden Einzelphotonen von einer Senderin (meist Alice genannt) zu einem Empfänger (meist Bob genannt) geschickt. Wichtig für die Funktion des Protokolls sind die folgenden Eigenschaften von Einzelphotonen:

- Ein Einzelphoton kann nicht kopiert werden
⇒ Man kann den Polarisationszustand eines Einzelphotons nur einmal messen.
- Ein Einzelphoton lässt sich nicht aufteilen.

Letztere Eigenschaft sorgt dafür, dass der Polarisationszustand nur dann scharf gemessen werden kann, wenn das Photon nur einen von zwei bekannten, zueinander rechtwinklige Zuständen annehmen kann.

Beispiel: Wenn ich weiß, dass ein Photon entweder in ℎ- oder in v-Richtung polarisiert ist (siehe Abbildung 1), kann ich einen Polarisator z.B. in v-Richtung ausrichten. Ein v-polarisiertes Photon kommt dann mit 100 % Wahrscheinlichkeit durch, ein ℎ-polarisiertes Photon nie. Somit habe ich den Zustand scharf gemessen. Fällt nun jedoch ein weder ℎnoch v-polarisiertes Photon auf den Polarisator, kann es sich nicht in v-Komponente und ℎ -Komponente aufteilen und kommt somit mit einer vom Winkel zur v-Richtung abhängigen Wahrscheinlichkeit durch. Da ich die Wahrscheinlichkeit aber nicht kenne, kann ich keine Aussage über den Polarisationszustand treffen (außer „nicht ℎ“,falls das Photon durchkommt, und „nicht v“, falls es nicht durchkommt).

Das obige Beispiel gilt für alle zueinander rechtwinkligen Zustandspaare. Ein solches Zustandspaar nennt man daher auch Messbasis. Beim BB84-Protokoll werden zwei um 45° zueinander verdrehte Messbasen verwendet (siehe Abbildung 1).

### 1.4 Ablauf des BB84-Protokolls

1. Alice schickt eine Zufallsfolge von Polarisationszuständen an Bob.
2. Bob weiß, dass jedes Einzelphoton entweder in der ℎ/v-Messbasis oder der +/− -Messbasis präpariert wurde. Daher misst er jedes Einzelphoton zufällig entweder in der ℎ/v-Basis oder der +/− -Basis:
- Angenommen, Alice schickt ein ℎ-polarisiertes Photon.
- Misst Bob das Photon in der ℎ/v-Basis, wird er auch eine ℎ-Polarisation messen.
- Misst Bob das Photon in der +/− -Basis, kann er nur eine +- oder eine − -Polarisation messen. Da die Messbasen ℎ/v und +/− um 45° zueinander verdreht sind, misst Bob mit einer Wahrscheinlichkeit von 50 % eine +-Polarisation und mit er einer Wahrscheinlichkeit von ebenfalls 50 % eine − -Polarisation.
3. Alice und Bob vergleichen für jedes gesendete Photon das gewählte Basissystem. Bei den Einzelphotonen, bei denen die Basissysteme übereinstimmen, muss Bob den von Alice

# Alice

# Bob

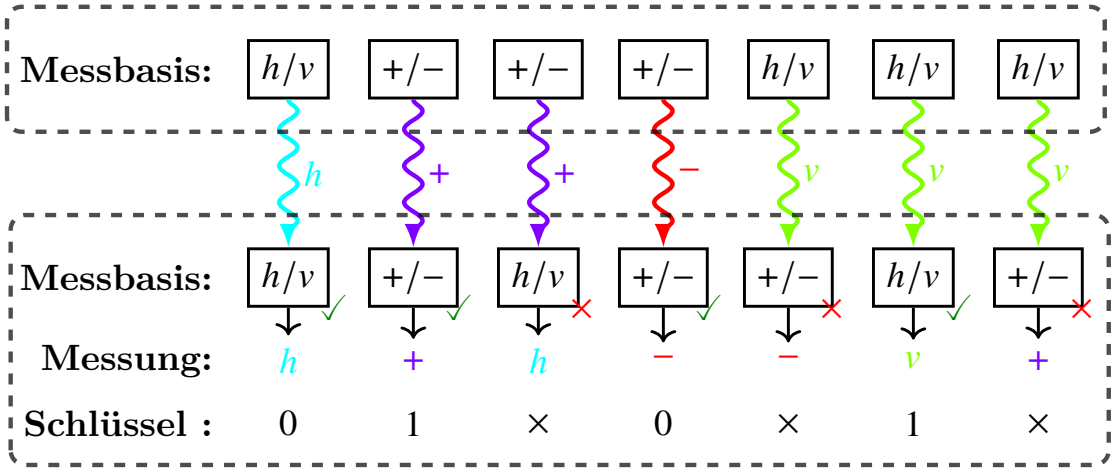
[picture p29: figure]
Messbasis:; Messung: Schlüssel :

Abbildung 2: Beispiel zum BB84-Protokoll.

gesendeten Polarisationszustand gemessen haben. Nur die Zustände dieser Photonen werden für die Schlüsselerstellung berücksichtigt.

4. Der Schlüssel wird folgendermaßen erstellt:
- ℎ-Polarisation oder − -Polarisation: 0
- v-Polarisation oder +-Polarisation: 1
5. Alice vergleicht die ersten paar Stellen des von ihr erstellten Schlüssels mit den ersten paar Stellen des von Bob erstellten Schlüssels (in der Realität etwa 1000 Stellen), um sicherzugehen, dass die Übertragung funktioniert hat.

Ein Beispiel findet sich in Abbildung 2.

### 1.5 Weitergehende Erklärungen

1. Der Vergleich der Messbasen kann über einen nicht abhörsicheren Kanal erfolgen. Die einzige Information, die darüber vermittelt wird, ist, bei welchen Messungen Bob die passende Messbasis gewählt hat. Die gemessenen Zustände selbst und somit auch den Schlüssel kennen weiterhin nur Alice und Bob.
2. Soll die Schlüsselübertragung abgehört werden, muss sich die abhörende Person (in der Regel als Eve bezeichnet, vom englischen eavesdropping) zwischen Alice und Bob schalten, da Einzelphotonen nicht kopiert werden können. Damit Bob nichts davon merkt, muss Eve die gemessenen Polarisationszustände weiter an Bob schicken. Da Eve mit einer Wahrscheinlichkeit von 50 % die „falsche“ Messbasis wählt, kommt es bei der Übertragung der Zustände von Alice zu Bob zu Fehlern. Diese werden ersichtlich, wenn Alice und Bob die ersten paar Stellen der von ihnen generierten Schlüssel untereinander vergleichen. So fällt der Abhörvorgang auf.

## 2 Das Experiment

### 2.1 Übersicht und Vorbereitung

Da Einzelphotonenquellen teuer und aufwänding zu justieren sind, wird in phyphox ein Analogieversuch durchgeführt. Hierbei werden gesendete Einzelphotonen durch farbige Patches auf dem Smartphone-Bildschirm simuliert (siehe Abbildung 3). Jedem Polarisationszustand ist genau eine Farbe zugewiesen. Um den Zustand zu messen, kann man mit der Kamera eines zweiten Geräts die Farbe des Patches und somit den gesendeten Polarisationszustand einlesen. Diese wird anschließend intern „gemessen“[1]

Es existieren insgesamt sieben phyphox-Experimente zum BB84-Protokoll. Hiervon sind drei für die Einstiegsversuche gedacht und vier für die Versuche für Fortgeschrittene. Die Experimente lassen sich als Bundle über den QR-Code oben rechts in der phyphox-App laden. Hierzu in phyphox auf das Plus-Symbol klicken und „Neues Experiment von einem QR-Code“ auswählen.

Für jeden der Versuche gibt es eine Tabelle auf dem Auswertungsbogen.

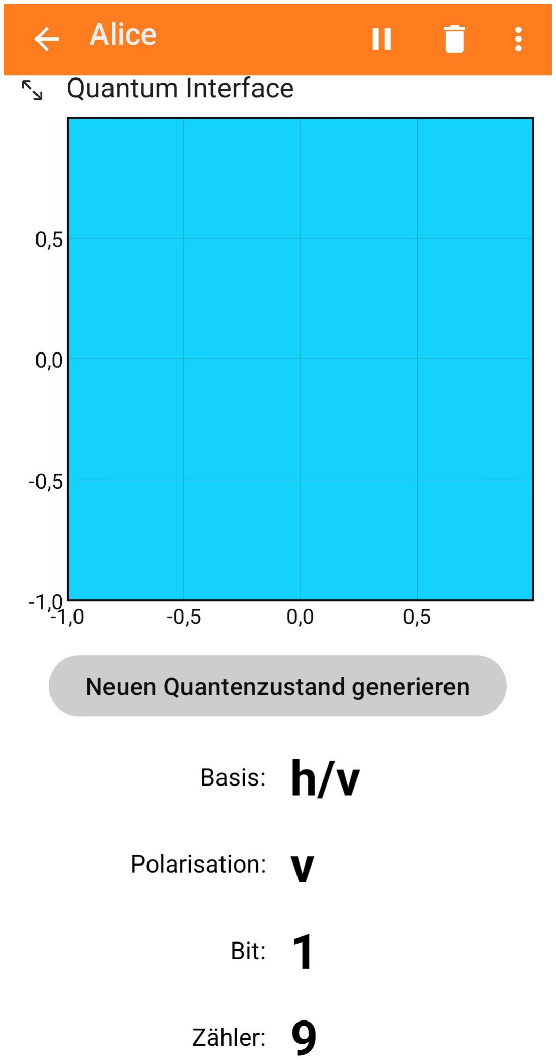
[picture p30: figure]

Abbildung 3: Screenshot
aus phyphox.

### 2.2 Einstiegsversuche

Diese Versuche sollten unbedingt vor den Versuchen für Fortgeschrittene durchgeführt werden. Die zugehörigen phyphox_Experimente sind:

- Alice: Schickt Polarisationszustände (als farbige Patches)
- Bob: „Misst“ Polarisationszustände, indem er Alices farbige Patches mit der Kamera ausliest.
- Eve: Fängt Polarisationszustände von Alice ab und schickt die gemessenen Zustände weiter an Bob.

[1]Sowohl zur Generierung als auch zur Messung der Zustände werden aus dem Rauschen des Beschleunigungssensors erzeugte Zufallszahlen verwendet. Diese werden von Pseudozufallszahlen überlagert, um die Funktion des Experiments auch auf Geräten mit defektem Beschleunigungssensor zu ermöglichen.

Versuch 1: Schlüsselerzeugung
Hierfür werden zwei Personen und zwei Smartphones benötigt. Eine Person bedient das Alice-Experiment, die andere Person bedient das Bob-Experiment.
Lasst Alice und Bob mithilfe des BB84-Protokolls einen Schlüssel erstellen. Nutzt hierfür die Tabelle auf dem Auswertungsbogen!

Das BB84-Protokoll

1. Alice generiert einen zufälligen Polarisationszustand.
2. Bob misst den Polarisationszustand mit einer zufälligen Messbasis.
3. Alice und Bob notieren sich die jeweils gewählte Basis und erzeugten bzw. gemessenen Polarisationszustand.
4. Alice und Bob notieren sich das zur Polarisationsrichtung zugeordnete Bit: 0 für ℎ oder −, 1 für v oder =.
5. Alice und Bob wiederholen die Schritte 1-4 mehrmals.
6. Alice und Bob vergleichen für jede Messung die Messbasen.
7. Stimmen die Messbasen überein, wird das zugehörige Bit für den Schlüssel ver-wendet (ansonsten nicht).

Versuch 2: Abhören
In diesem Versuch sollt ihr untersuchen, was passiert, wenn eine dritte Person versucht, die Schlüsselübertragung abzuhören. Hierzu ist das Experiment Eve gedacht. Eve schaltet sich zwischen Alice und Bob. Sie fängt Einzelphotonen von Alice ab und misst die Polarisationszustände. Die gemessenen Zustände schickt sie weiter an Bob.
a) Führt das BB84-Protokoll wie bisher aus, wobei sich Eve zwischen Alice und Bob schaltet. Nutzt hierfür die Tabelle auf dem Auswertungsbogen!
Da Alice und Bob nichts von Eve wissen, vergleichen sie bei der Schlüsselerstellung auch weiterhin ihre Messbasen miteinander.
b) Vergleicht den von Alice erstellten Schlüssel mit dem von Bob erstellten Schlüssel.
- Was fällt auf?
- Wie lässt sich eure Beobachtung erklären?

### 2.3 Versuche für Fortgeschrittene

In diesen Versuchen werden insgesamt vier phyphox-Experimente verwendet:

- V-Alice
- V-Bob
- V-Eve
- Eve, u there?

V-Alice unterscheidet sich von Alice dahingehend, dass die gesendeten Polarisationszustänge nicht mehr direkt einsehbar sind. Dies wird durch zwei Maßnahmen erreicht:

1. Die generierten Zustände (max. 20) werden in einem separaten Reiter gespeichert, sodass sie zu einem späteren Zeitpunkt in eine Tabelle übertragen werden können.
2. Die Farben sind nun nicht mehr eindeutig einem Polarisationszustand zugeordnet. Stattdessen wird das Farbsignal über Pseudozufallszahlen verschlüsselt.

V-Bob unterscheidet sich von Bob dahingehend, dass er das Farbsignal wieder entschlüsseln kann. V-Eve und Eve unterscheiden sich in allen Aspekten, die V-Alice und V-Bob betreffen.

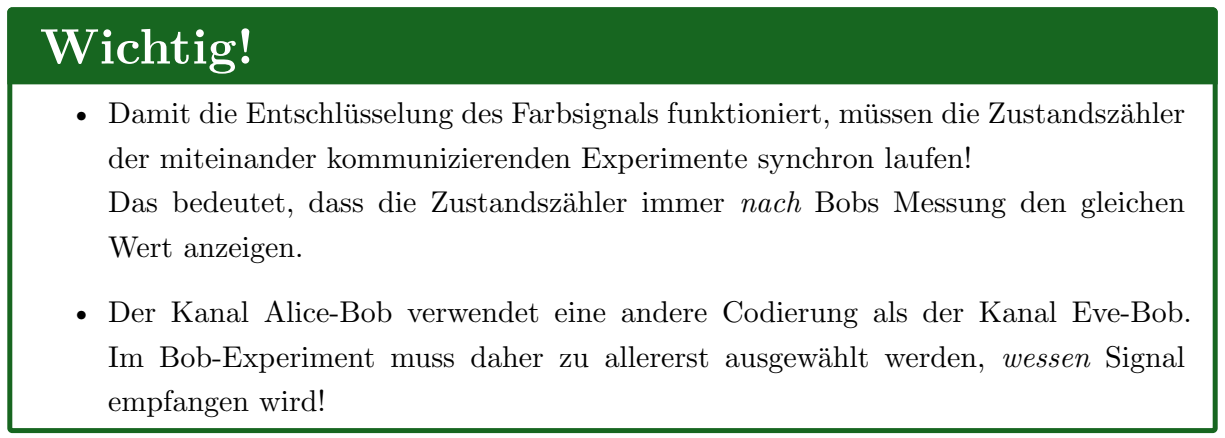
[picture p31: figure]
Wichtig!; Wert anzeigen.; empfangen wird!

- Damit die Entschlüsselung des Farbsignals funktioniert, müssen die Zustandszähler der miteinander kommunizierenden Experimente synchron laufen!
Das bedeutet, dass die Zustandszähler immer nach Bobs Messung den gleichen
- Der Kanal Alice-Bob verwendet eine andere Codierung als der Kanal Eve-Bob. Im Bob-Experiment muss daher zu allererst ausgewählt werden, wessen Signal

Das Ziel der Nicht-Einsehbarkeit der gesendeten Zustände ist eine Annäherung der Analogie an die Realität. Alice und Bob können dort während der Photonenübertragung schließlich nicht prüfen, ob die Schlüsselübertragung wie vorgesehen funktioniert hat.

Versuch 3: Verdeckte Schlüsselerzeugung Dieser Versuch entspricht Versuch 1.

Versuch 4: Verdecktes Abhören
Dieser Versuch entspricht Versuch 2.

Versuch 5: Eve, u there?
Dieser Versuch wird wie Versuch 3 durchgeführt, mit folgender Änderung:
Statt „V-Alice“ komt das Experiment „Eve, u there?“ zum Einsatz. Es funktioniert genauso wie „V-Alice“ (d.h. Bob stellt den Kanal Alice-Bob ein), allerdings kann über einen separaten Reiter Eve zugeschaltet werden, die dann intern den generierten Zustand misst und diesen als Farbsignal ausgibt.
Für Bob ist nicht ersichtlich, ob er das Farbsignal von Alice oder von Eve bekommt. Das Ziel des Versuchs ist es, dass Bob erkennt, ob die Schlüsselübertragung abgehört wurde oder nicht.

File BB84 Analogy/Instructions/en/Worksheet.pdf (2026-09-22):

®

# The BB84 protocol

## – Worksheet –

## The BB84 protocol

1. Alice generates a random polarisation state.
2. Bob measures the polarisation state using a random measurement basis.
3. Alice and Bob record the basis they each chose and the polarisation state they generated / measured.
4. Alice and Bob record the bit associated with the polarisation direction: 0 for ℎ or −, 1 for v or =.
5. Alice generates a random polarisation state.
6. Bob measures the polarisation state using a random measurement basis.
7. Alice and Bob record the basis they each chose and the polarisation state they generated / measured.
8. Alice and Bob record the bit associated with the polarisation direction: 0 for ℎ or −, 1 for v or =.

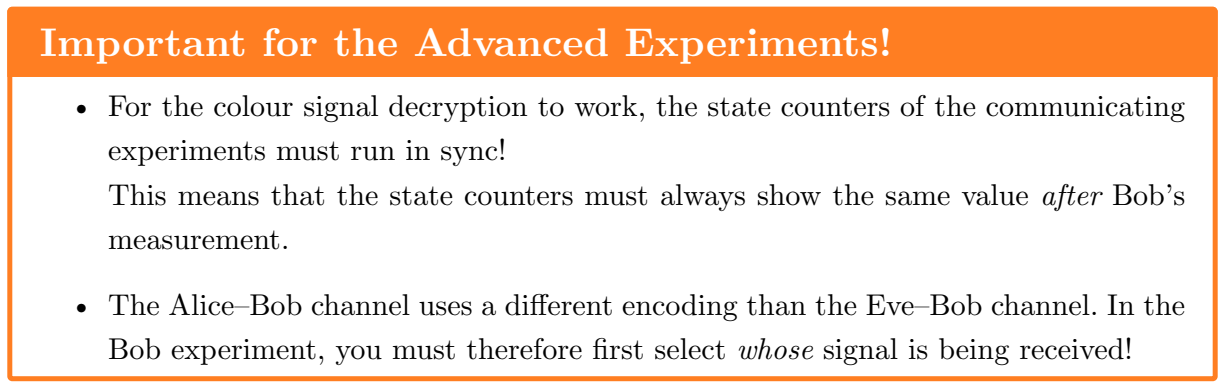
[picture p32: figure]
Important for the Advanced Experiments!; experiments must run in sync!; measurement.

- For the colour signal decryption to work, the state counters of the communicating

This means that the state counters must always show the same value after Bob’s

- The Alice–Bob channel uses a different encoding than the Eve–Bob channel. In the Bob experiment, you must therefore first select whose signal is being received!

This document is licensed under CC BY 4.0. https://creativecommons.org/licenses/by/4.0/. Author: Johannes Schlaf

Experiment 1: Key generation

Photon Example Example 1 2

3

4

5

6

7

8

9 10 11 12 13 14 15 16 17 18 19 20

Alice Basis

ℎ

/

v

ℎ

/

v

State

v

v

Bit 1 1

Bob Basis

+

/

−

ℎ

/

v

State

+

v

Bit 1 1

Agreement

of bases

×

✓

Key

/

1

Experiment 2: Eavesdropping

Photon 1 2

3

4

5

6

7

8

9 10 11 12 13 14 15 16 17 18 19 20

Alice Basis

State
Bit

Eve Basis

State
Bit

Bob Basis

State
Bit

Agreement
of bases

(Alice/Bob)
Alice’s key
Bob’s key

Experiment 3: Covert key generation

Photon 1 2 3 4 5 6 7 8 9 10 11 12 13 14 15 16 17 18 19 20

Alice Basis

State
Bit

Bob Basis

State
Bit

Agree-

ment of
bases
Key

Experiment 4: Covert eavesdropping

Photon 1 2

3

4

5

6

7

8

9 10 11 12 13 14 15 16 17 18 19 20

Alice Basis

State
Bit

Eve Basis

State
Bit

Bob Basis

State
Bit

Agreement
of bases

(Alice/Bob)
Alice’s key
Bob’s key

Experiment 5: Eve, u there?

Photon 1 2

3

4

5

6

7

8

9 10 11 12 13 14 15 16 17 18 19 20

Alice Basis

State
Bit

Bob Basis

State
Bit

Agreement
of bases

Alice’s key
Bob’s key

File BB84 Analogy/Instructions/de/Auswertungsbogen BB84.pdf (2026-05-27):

®

# Das BB84-Protokoll

## – Auswertung –

### Das BB84-Protokoll

1. Alice generiert einen zufälligen Polarisationszustand.
2. Bob misst den Polarisationszustand mit einer zufälligen Messbasis.
3. Alice und Bob notieren sich die jeweils gewählte Basis und erzeugten bzw. gemes-senen Polarisationszustand.
4. Alice und Bob notieren sich das zur Polarisationsrichtung zugeordnete Bit: 0 für ℎ oder −, 1 für v oder =.
5. Alice und Bob wiederholen die Schritte 1-4 mehrmals.
6. Alice und Bob vergleichen für jede Messung die Messbasen.
7. Stimmen die Messbasen überein, wird das zugehörige Bit für den Schlüssel verwendet (ansonsten nicht).

### Wichtig für die Experimente für Fortgeschrittene!

- Damit die Entschlüsselung des Farbsignals funktioniert, müssen die Zustandszähler der miteinander kommunizierenden Experimente synchron laufen!
Das bedeutet, dass die Zustandszähler immer nach Bobs Messung den gleichen Wert anzeigen.
- Der Kanal Alice-Bob verwendet eine andere Codierung als der Kanal Eve-Bob. Im Bob-Experiment muss daher zu allererst ausgewählt werden, wessen Signal empfangen wird!

This document is licensed under CC BY 4.0. https://creativecommons.org/licenses/by/4.0/. Author: Johannes Schlaf

Versuch 1: Schlüsselerzeugung

Photon Bsp. Bsp. 1 2

3

4

5

6

7

8

9 10 11 12 13 14 15 16 17 18 19 20

Alice Basis

ℎ

/

v

ℎ

/

v

Zustand

v

v

Bit 1 1

Bob Basis

+

/

−

ℎ

/

v

Zustand

+

v

Bit 1 1

Überein- stimmung
der Basis

×

✓

Schlüssel

/

1

Versuch 2: Abhören

Photon 1 2

3

4

5

6

7

8

9 10 11 12 13 14 15 16 17 18 19 20

Alice Basis

Zustand
Bit

Eve Basis

Zustand
Bit

Bob Basis

Zustand
Bit

# Übereinstim- mung der Basis

(Alice/Bob)

Alices Schlüssel
Bobs Schlüssel

Versuch 3: Verdeckte Schlüsselerzeugung

Photon 1 2 3 4 5 6 7 8 9 10 11 12 13 14 15 16 17 18 19 20

Alice Basis

Zustand
Bit

Bob Basis

Zustand
Bit

# Überein- stimmmung

der Basis
Schlüssel

Versuch 4: Verdecktes Abhören

Photon 1 2

3

4

5

6

7

8

9 10 11 12 13 14 15 16 17 18 19 20

Alice Basis

Zustand
Bit

Eve Basis

Zustand
Bit

Bob Basis

Zustand
Bit

# Übereinstim- mung der Basis

(Alice/Bob)

Alices Schlüssel
Bobs Schlüssel

Versuch 5: Eve, u there?

Photon 1 2

3

4

5

6

7

8

9 10 11 12 13 14 15 16 17 18 19 20

Alice Basis

Zustand
Bit

Bob Basis

Zustand
Bit

# Übereinstim- mung der Basis

Alices Schlüssel
Bobs Schlüssel

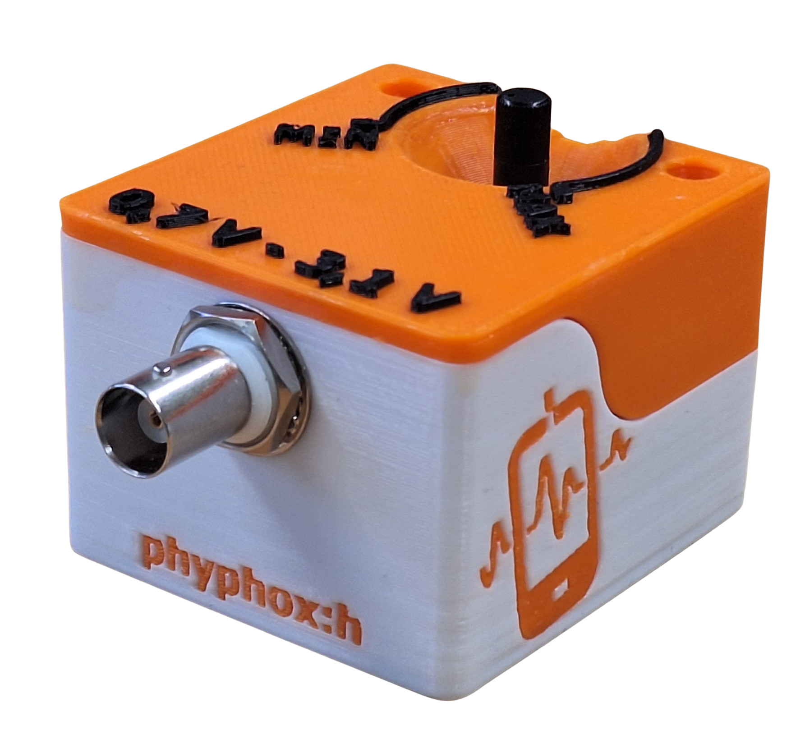
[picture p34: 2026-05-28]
Measuring Planck's Constant/Instructions/typ-files/en/Figures/h-box.png

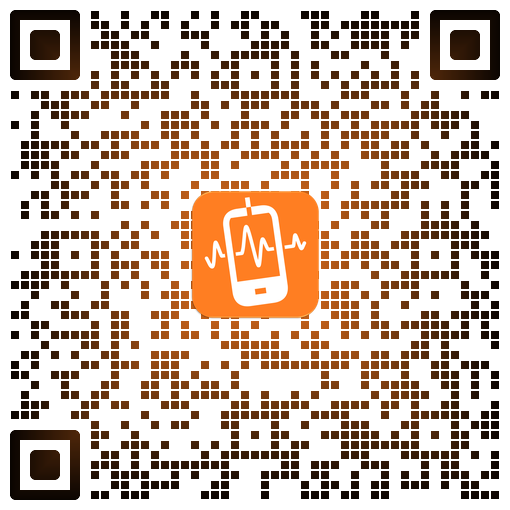
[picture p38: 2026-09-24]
BB84 Analogy/Instructions/typ-files/en/Figures/QR_QC-Bundle.png

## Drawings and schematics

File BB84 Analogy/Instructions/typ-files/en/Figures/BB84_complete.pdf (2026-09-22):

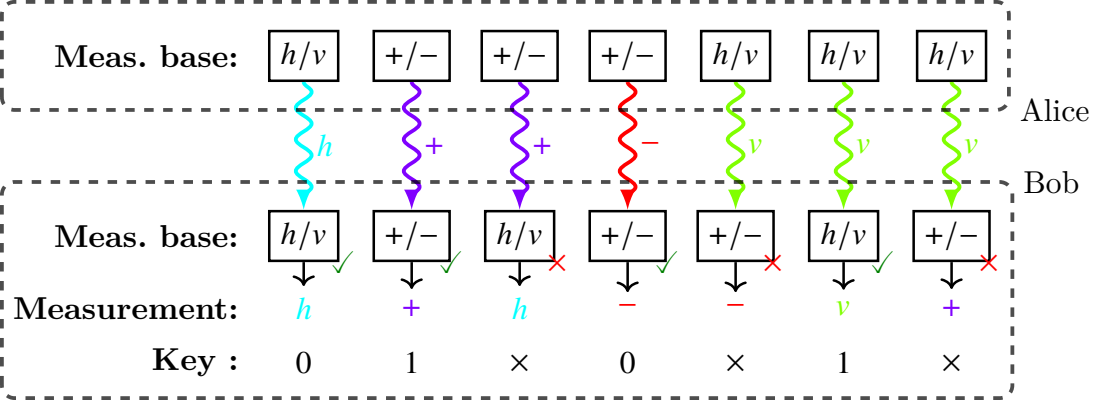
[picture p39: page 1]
Meas. base:; Measurement: Key :; Alice; Bob

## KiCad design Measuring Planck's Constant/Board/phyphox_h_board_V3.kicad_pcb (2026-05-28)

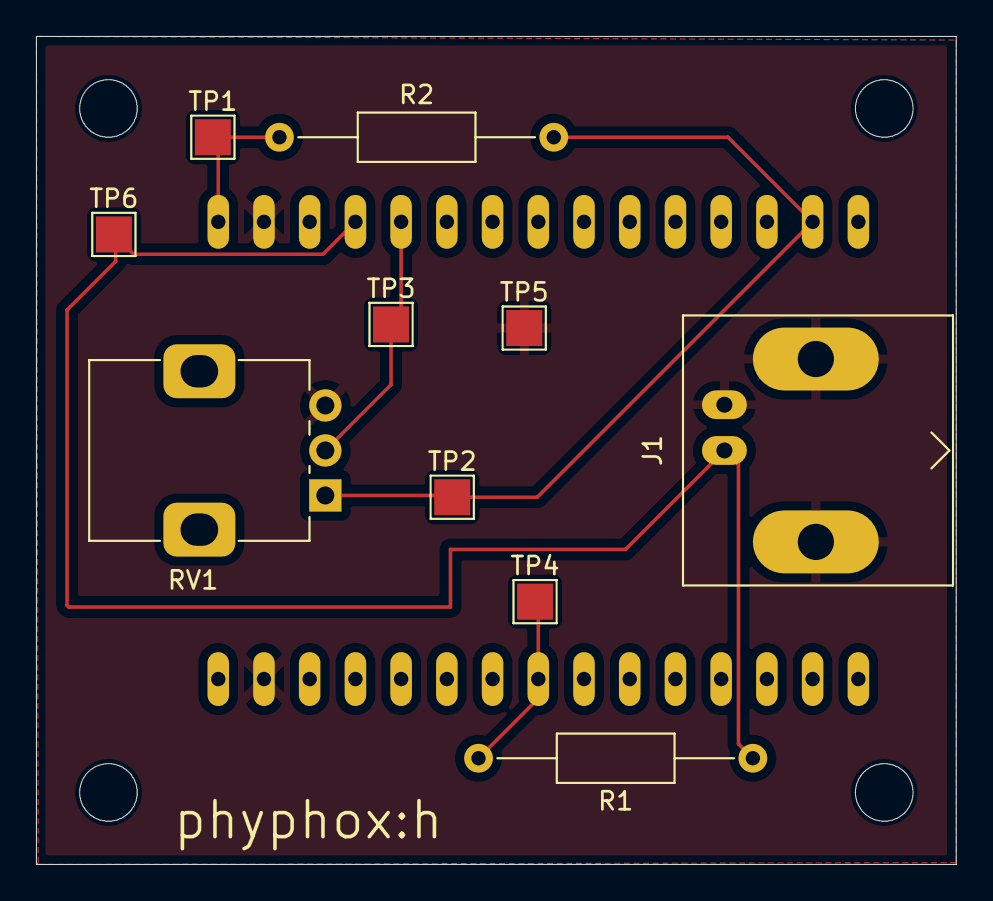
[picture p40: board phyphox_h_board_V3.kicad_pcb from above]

Board: 2 copper layers, 51.1 x 46.0 mm, 15 parts (1 on the bottom side), 6 nets.

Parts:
H1, H2, H3, H4: MountingHole; MountingHole_3.2mm_M3
J1: Conn_Coaxial_Small; BNC_Amphenol_B6252HB-NPP3G-50_Horizontal
R1, R2: 100R; R_Axial_DIN0207_L6.3mm_D2.5mm_P15.24mm_Horizontal
RV1: R_Potentiometer; Potentiometer_Alps_RK09K_Single_Vertical
TP1, TP2, TP3, TP4, TP5, TP6: TestPoint; TestPoint_Pad_2.0x2.0mm
U1: NodeMCU ESP32; NodeMCU-ESP32

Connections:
GND: J1.2 (Ext), RV1.3, TP5.1, U1.2 (GND), U1.29 (GND)
unnamed: J1.1 (In), R1.1, TP6.1, U1.4 (D2)
unnamed: R2.1, TP1.1, U1.1 (3,3V)
unnamed: RV1.2, TP3.1, U1.5 (D4)
unnamed: R2.2, RV1.1, TP2.1, U1.14 (D22)
unnamed: R1.2, TP4.1, U1.23 (D25)

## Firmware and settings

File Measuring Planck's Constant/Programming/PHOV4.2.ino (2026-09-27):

#include <math.h>
#include <phyphoxBle.h>

// Different for each box
const char* ssid = "phyphox:h (V4.2) 38";

// Functions (without write_File, append_File)
void simon_says();
int reverse_cal_mapping(float);
int map_voltage_to_bit(int, int, int);
float current_mapping(int);
float cal_OUT_mapping(int, int);
float cal_IN_mapping(int);


// Pins
int pinOUT = 25;
int pinPOT = 4;
int pinRES = 2;

// phyphox vars
int mode;
int period; // 
float voltageTARGET; // V
float voltageLOW; // V
float voltageHIGH; // V

// General vars
float voltageOUT; // V
int bvoltageOUT;
float currentRES; // mA
float voltageRES; // V
int bvoltageRES;
float cal_factor;

// Vars for Mode 0 (manual)
int bvoltagePOT;
int bvoltageMIN;
int bvoltageMAX;

// Vars for Mode 2 (auto)
int bvoltageINC;
int cad; // ms
int bvoltageLOW;
int bvoltageHIGH;
int periodInUse;

uint8_t PLA[22221] = {80,75,3,4,20,0,8,0,8,0,153,182,56,93,0,0,0,0,0,0,0,0,0,0,0,0,26,0,32,0,50,
48,50,54,48,57,50,52,95,80,72,79,86,52,46,50,45,76,46,112,104,121,112,104,111,120,117,120,11,0,1,
4,0,0,0,0,4,0,0,0,0,85,84,13,0,7,162,141,181,106,165,141,181,106,214,251,180,106,237,125,201,
146,226,216,146,232,190,205,250,31,120,97,118,237,101,22,55,19,137,153,178,172,52,147,132,4,26,24,133,4,226,
90,117,154,102,9,141,104,64,136,101,255,198,235,229,253,134,183,233,222,213,190,63,162,191,228,29,1,17,1,193,
16,130,136,204,91,183,234,101,153,85,128,144,252,248,124,220,143,251,57,250,226,27,169,111,120,235,194,74,13,66,
211,115,127,121,128,63,151,161,135,130,237,201,162,173,254,242,160,186,15,95,255,245,95,10,224,223,151,200,140,108,
245,235,208,22,93,217,250,223,97,1,243,220,48,18,221,232,75,105,247,195,254,46,89,140,84,221,11,210,175,163,
24,252,24,59,133,161,145,134,166,28,126,41,61,253,242,120,167,103,123,193,215,50,4,65,162,8,126,221,126,219,
255,164,168,161,28,152,126,4,16,250,218,83,197,48,14,212,176,16,25,106,97,229,217,145,168,171,5,49,42,136,
110,129,193,219,5,81,23,77,128,200,246,87,219,212,141,168,96,186,145,234,134,102,148,22,116,115,165,186,5,41,
221,254,40,139,142,26,136,5,79,43,136,133,208,17,131,8,144,237,2,72,174,82,48,21,213,141,76,205,220,15,
18,25,96,56,195,179,149,167,225,192,67,217,15,96,188,207,5,126,199,168,66,245,115,249,243,151,210,33,166,123,
228,77,25,252,170,121,129,35,70,191,60,72,98,168,214,171,15,95,77,30,29,140,19,136,238,232,30,2,254,245,
89,206,192,57,29,124,234,101,255,107,147,24,34,128,191,88,52,165,235,42,248,192,205,56,27,31,241,227,234,44,
134,21,181,110,56,252,152,175,48,195,222,90,72,253,37,143,47,209,206,146,242,49,214,94,14,156,165,109,96,19,
223,163,59,68,199,155,57,250,26,237,135,58,19,44,154,129,234,104,82,42,9,188,56,93,178,19,219,51,45,71,
168,154,188,103,242,115,139,178,231,180,5,249,218,34,244,184,114,73,211,42,131,214,108,227,186,65,165,50,117,227,
85,105,178,112,3,100,48,139,103,131,82,164,104,139,168,53,95,5,141,202,176,14,199,101,215,168,211,58,70,233,
227,41,54,23,150,61,146,70,168,50,74,141,244,169,81,166,117,164,135,82,130,57,53,82,90,71,251,184,200,33,
19,12,239,35,3,220,19,165,133,239,145,136,181,28,153,236,88,76,146,117,123,132,88,172,225,199,3,71,215,49,
214,199,40,138,8,218,109,112,51,54,166,59,78,181,46,98,8,69,91,164,101,77,195,94,111,4,33,212,173,48,
166,37,98,92,111,137,81,57,241,7,65,79,26,14,23,125,119,24,160,97,89,162,25,115,17,77,19,132,208,67,
177,49,100,134,24,25,196,45,15,157,149,7,229,113,58,77,240,170,41,34,86,73,142,87,137,48,241,137,25,217,
166,58,53,172,171,194,203,90,25,65,170,195,190,214,161,13,113,70,33,163,117,59,28,82,179,34,166,85,68,142,
161,39,115,93,156,181,210,186,62,112,6,77,70,45,137,182,147,214,210,53,219,95,44,201,132,41,42,6,10,85,
90,11,111,81,47,207,230,200,216,239,118,39,125,13,107,184,140,218,83,19,212,152,80,84,175,197,153,85,215,208,
199,75,162,170,58,182,27,36,229,209,84,171,140,67,113,218,224,240,58,219,23,26,157,100,132,217,84,191,154,38,
184,58,94,8,43,198,115,134,240,176,46,152,195,174,52,224,210,104,93,164,130,185,109,162,52,94,111,47,218,241,
40,70,27,206,0,243,5,152,116,252,198,36,30,122,84,15,27,107,120,169,220,181,170,200,42,26,118,39,11,169,
220,129,80,191,24,45,122,246,188,53,26,251,155,196,159,208,250,88,226,124,78,103,155,45,193,23,83,198,71,198,
104,111,81,196,199,221,102,77,177,135,115,2,231,105,178,67,57,206,124,189,176,217,246,6,197,109,5,175,91,20,
228,70,197,142,206,195,131,17,217,48,108,95,8,235,100,21,47,15,7,158,87,157,123,235,117,18,35,253,117,67,
41,83,141,137,164,135,81,83,168,22,43,29,190,67,165,52,78,142,152,56,236,247,250,9,208,239,84,192,117,158,
197,171,85,187,186,44,14,72,102,41,135,190,108,249,16,162,139,80,45,148,200,37,85,83,69,209,92,108,58,4,
212,104,246,102,146,51,209,81,146,86,125,224,201,132,181,84,236,198,195,178,160,187,228,16,119,125,137,142,234,221,
165,63,102,201,218,100,146,120,205,246,198,230,6,76,185,194,245,55,99,134,73,124,30,74,39,230,68,25,163,93,
25,145,117,147,42,85,208,121,39,80,155,237,65,20,180,75,4,100,233,181,178,160,160,152,25,149,171,140,11,79,
80,88,237,12,25,158,71,219,51,154,74,177,57,105,142,87,4,94,244,41,27,171,147,253,177,231,35,229,132,107,
16,30,13,201,26,201,115,101,191,231,179,42,222,89,72,222,218,83,76,20,39,176,118,117,216,234,149,186,27,223,
172,10,203,121,175,214,247,40,104,144,182,108,122,46,214,61,122,6,219,85,207,199,56,124,180,33,60,36,234,0,
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

void setup() {
  Serial.begin(9600);
  while (!Serial) {delay(100);}
  
  // Enable Voltages
  pinMode(pinOUT, OUTPUT); // DAC-Output
  pinMode(pinPOT, INPUT); // Spannung am Poti einlesen
  pinMode(pinRES, INPUT); // Spannung am Vorwiderstand einlesen


  // Set up Bluetooth connection
  PhyphoxBLE::start(ssid, &PLA[0], sizeof(PLA)); // phyphox-Verbindung starten
  //PhyphoxBLE::setMTU(185); // Byte-Max hochsetzen
  PhyphoxBLE::configHandler=&simon_says; // phyphox-Input ermöglichen

  // Set default values
  bvoltagePOT = 4095;
  bvoltageMIN = 50;
  bvoltageMAX = 254;
  bvoltageINC = 1;
  cad = 40;
  bvoltageOUT = bvoltageMIN + 10;
}

void loop() {
  // Actual purpose
  PhyphoxBLE::poll();
  delay(25);
  switch(mode) {
    case 2: // auto mode
      bvoltageLOW = reverse_cal_mapping(voltageLOW);
      bvoltageHIGH = reverse_cal_mapping(voltageHIGH);
      if (bvoltageLOW == bvoltageHIGH) {bvoltageHIGH++; period=1;}
      cad = (int) max(period*1000/(bvoltageHIGH-bvoltageLOW) + 0.5, 20.0);
      periodInUse = period;
      for (int bvoltageOUT=bvoltageLOW; bvoltageOUT <= bvoltageHIGH; bvoltageOUT=bvoltageOUT+bvoltageINC) {
        voltageOUT = cal_OUT_mapping(bvoltageOUT, 1);
        dacWrite(pinOUT, bvoltageOUT);
        bvoltageRES = analogRead(pinRES);
        voltageRES = cal_IN_mapping(bvoltageRES);
        currentRES = current_mapping(voltageRES);
        PhyphoxBLE::write(voltageOUT, currentRES);
        delay(cad);
        if(mode == 0 || mode == 1 || period != periodInUse){break;}
      }
      break;
    case 0: // manual mode
      bvoltagePOT = analogRead(pinPOT);
      bvoltageOUT = map_voltage_to_bit(bvoltagePOT, bvoltageMIN, bvoltageMAX);
      voltageOUT = cal_OUT_mapping(bvoltageOUT, 0);
      dacWrite(pinOUT, bvoltageOUT);
      bvoltageRES = analogRead(pinRES);
      voltageRES = cal_IN_mapping(bvoltageRES);
      currentRES = current_mapping(voltageRES);
      Serial.print(bvoltageRES);
      Serial.print(", ");
      Serial.print(voltageOUT);
      Serial.print(", ");
      Serial.println(currentRES);
      PhyphoxBLE::write(voltageOUT, currentRES);
      break;
    case 1: // target voltage mode
      bvoltageOUT = reverse_cal_mapping(voltageTARGET);
      voltageOUT = cal_OUT_mapping(bvoltageOUT, 0);
      dacWrite(pinOUT, bvoltageOUT);
      bvoltageRES = analogRead(pinRES);
      voltageRES = cal_IN_mapping(bvoltageRES);
      currentRES = current_mapping(voltageRES);
      PhyphoxBLE::write(voltageOUT, currentRES);
      break;
    default: dacWrite(pinOUT, 0); voltageOUT = 0; currentRES = 0; PhyphoxBLE::write(voltageOUT, currentRES);
  }
}

void simon_says() {
  // Read array
  uint8_t my_array[16];
  PhyphoxBLE::read(&my_array[0], 16);
  memcpy(&mode, &my_array[0], 2);
  memcpy(&voltageTARGET, &my_array[2], 4);
  memcpy(&period, &my_array[6], 2);
  memcpy(&voltageLOW, &my_array[8], 4);
  memcpy(&voltageHIGH, &my_array[12], 4);

  // Safety net for certain variables
  voltageTARGET = max( min(voltageTARGET, (float) 3.2), (float) 0.0 );
  voltageLOW = max( min(voltageLOW, (float) 3.2), (float) 0.0 );
  voltageHIGH = max( min(voltageHIGH, (float) 3.2), (float) 0.0 );
}

int reverse_cal_mapping(float i) {
  return( (int) (i*255/3.3 + 0.5) );
}

int map_voltage_to_bit(int input, int U_min, int U_max) {
  float output;
  output = (U_min-U_max)*input/4095 + U_max + 0.5;
  return(min(U_max, (int) output));
}

float current_mapping(float input) {
  float output;
  output = (voltageOUT-input)*10;
  return(output);
}

float cal_OUT_mapping(int i, int j) {
  switch(j) {
    case 0: // Default
      switch(i) {
        case 50: return(0.6872882395916667);
        case 51: return(0.7012955844416666);
        case 52: return(0.7162220478083333);
        case 53: return(0.7243470500083333);
        case 54: return(0.7399720599166666);
        case 55: return(0.757729426);
        case 56: return(0.7639058927750001);
        case 57: return(0.7749353051333334);
        case 58: return(0.7834279537416666);
        case 59: return(0.8010014692916666);
        case 60: return(0.8135382383833332);
        case 61: return(0.8279500057166667);
        case 62: return(0.8412220626833333);
        case 63: return(0.8502661834);
        case 64: return(0.8635382354166667);
        case 65: return(0.88103821875);
        case 66: return(0.8898617476249999);
        case 67: return(0.8965897013749999);
        case 68: return(0.9107073495666667);
        case 69: return(0.9262955933833334);
        case 70: return(0.9452661971416667);
        case 71: return(0.9513691316083333);
        case 72: return(0.9629132598666668);
        case 73: return(0.9756706456166667);
        case 74: return(0.9871780177);
        case 75: return(1.0039059370333332);
        case 76: return(1.0161118307500001);
        case 77: return(1.0269206364166668);
        case 78: return(1.0370676718333334);
        case 79: return(1.05074413625);
        case 80: return(1.0678764581666669);
        case 81: return(1.0799352725000002);
        case 82: return(1.09434703975);
        case 83: return(1.1046044427500001);
        case 84: return(1.116552919);
        case 85: return(1.126699994);
        case 86: return(1.1410382190833332);
        case 87: return(1.15383233625);
        case 88: return(1.1652661164166667);
        case 89: return(1.1770308813333332);
        case 90: return(1.19004559525);
        case 91: return(1.2079500257500002);
        case 92: return(1.2173985440833333);
        case 93: return(1.2289059061666667);
        case 94: return(1.2391265033333334);
        case 95: return(1.2545676233333332);
        case 96: return(1.2688691319166665);
        case 97: return(1.2828764023333332);
        case 98: return(1.2939794065);
        case 99: return(1.3070676326666666);
        case 100: return(1.3164058825833331);
        case 101: return(1.3307809036666667);
        case 102: return(1.3453764916666664);
        case 103: return(1.3555235664166665);
        case 104: return(1.3676191469166668);
        case 105: return(1.3814794419166665);
        case 106: return(1.3940529725);
        case 107: return(1.40666326875);
        case 108: return(1.4159647425);
        case 109: return(1.4314794542500002);
        case 110: return(1.44427357125);
        case 111: return(1.4578029811666666);
        case 112: return(1.4703029891666666);
        case 113: return(1.4834279915000002);
        case 114: return(1.4941632948333334);
        case 115: return(1.5072882574166666);
        case 116: return(1.5218470793333334);
        case 117: return(1.5305970908333333);
        case 118: return(1.5442735849166667);
        case 119: return(1.5615897376666668);
        case 120: return(1.569751511);
        case 121: return(1.5798985758333335);
        case 122: return(1.5928397575000002);
        case 123: return(1.6057809293333336);
        case 124: return(1.61618535725);
        case 125: return(1.6321412424166666);
        case 126: return(1.636479447333333);
        case 127: return(1.6432074308333335);
        case 128: return(1.6496044695833332);
        case 129: return(1.6603029666666669);
        case 130: return(1.6725824077499998);
        case 131: return(1.6854132810833333);
        case 132: return(1.6990529994166668);
        case 133: return(1.7125824191666665);
        case 134: return(1.7228397626666667);
        case 135: return(1.73655302325);
        case 136: return(1.7459647654166668);
        case 137: return(1.7585015098333334);
        case 138: return(1.77537650875);
        case 139: return(1.7853397726666667);
        case 140: return(1.79460447025);
        case 141: return(1.8090530036666665);
        case 142: return(1.822030911833333);
        case 143: return(1.8364426593333334);
        case 144: return(1.8453765113333331);
        case 145: return(1.86100153125);
        case 146: return(1.87453094125);
        case 147: return(1.8867000539999998);
        case 148: return(1.8940162160833336);
        case 149: return(1.9095676342499999);
        case 150: return(1.9192735056666665);
        case 151: return(1.9291264414166667);
        case 152: return(1.94059707725);
        case 153: return(1.9561852912500002);
        case 154: return(1.9690897266666667);
        case 155: return(1.9846780101666668);
        case 156: return(1.9931338825833336);
        case 157: return(2.004530996166667);
        case 158: return(2.023354411083333);
        case 159: return(2.0408912302499997);
        case 160: return(2.0494206349166664);
        case 161: return(2.0586486458333333);
        case 162: return(2.07192063325);
        case 163: return(2.084052960166667);
        case 164: return(2.095339775166667);
        case 165: return(2.1061118047500003);
        case 166: return(2.116295635666667);
        case 167: return(2.132986784);
        case 168: return(2.142692744583333);
        case 169: return(2.1562589406666666);
        case 170: return(2.1670677065833335);
        case 171: return(2.1782809893333335);
        case 172: return(2.191369175916667);
        case 173: return(2.204494198166667);
        case 174: return(2.2207809489166666);
        case 175: return(2.229420662);
        case 176: return(2.24556032825);
        case 177: return(2.2577661870833334);
        case 178: return(2.2703765036666668);
        case 179: return(2.279898623666667);
        case 180: return(2.29144275175);
        case 181: return(2.307876507333333);
        case 182: return(2.315927982333333);
        case 183: return(2.3275089263333335);
        case 184: return(2.3445676564166664);
        case 185: return(2.356589774333333);
        case 186: return(2.3659647505);
        case 187: return(2.3813691935);
        case 188: return(2.392288287583333);
        case 189: return(2.405523598416667);
        case 190: return(2.4176927606666663);
        case 191: return(2.425155977416667);
        case 192: return(2.4408177335);
        case 193: return(2.4517736633333334);
        case 194: return(2.4652295309166665);
        case 195: return(2.4831339914166666);
        case 196: return(2.4918103814166668);
        case 197: return(2.5056707063333334);
        case 198: return(2.5134280324166665);
        case 199: return(2.526332477583334);
        case 200: return(2.5358177820833334);
        case 201: return(2.5506339668333338);
        case 202: return(2.5619574387500004);
        case 203: return(2.5755972065833337);
        case 204: return(2.5851559638333335);
        case 205: return(2.6013691823333334);
        case 206: return(2.6138692498333334);
        case 207: return(2.62967803075);
        case 208: return(2.63956775275);
        case 209: return(2.6527662476666665);
        case 210: return(2.663575073083333);
        case 211: return(2.6732074617499997);
        case 212: return(2.687582453);
        case 213: return(2.7027295032499996);
        case 214: return(2.711626589333333);
        case 215: return(2.7227662403333333);
        case 216: return(2.735486865416666);
        case 217: return(2.752067764583334);
        case 218: return(2.7626192370833333);
        case 219: return(2.772288342333333);
        case 220: return(2.7809648315);
        case 221: return(2.7955971360833334);
        case 222: return(2.8080603877500003);
        case 223: return(2.8222883146666664);
        case 224: return(2.834126571833333);
        case 225: return(2.8452295461666663);
        case 226: return(2.855413357333333);
        case 227: return(2.869273583);
        case 228: return(2.883354485);
        case 229: return(2.8957809806666663);
        case 230: return(2.9077663024166664);
        case 231: return(2.9200456937499997);
        case 232: return(2.9329868555000003);
        case 233: return(2.9426560203333336);
        case 234: return(2.9546045265000003);
        case 235: return(2.9689794779166663);
        case 236: return(2.9784647424166666);
        case 237: return(2.9868103266666663);
        case 238: return(3.0013323825);
        case 239: return(3.0133911966666664);
        case 240: return(3.027508874666667);
        case 241: return(3.03846474475);
        case 242: return(3.0483545660833338);
        case 243: return(3.0599354109166663);
        case 244: return(3.068942805083333);
        case 245: return(3.079825143083333);
        case 246: return(3.0916266243333332);
        case 247: return(3.101222197166667);
        case 248: return(3.1115162968333334);
        case 249: return(3.1234280069166664);
        case 250: return(3.1313324769166666);
        case 251: return(3.1394574841666665);
        case 252: return(3.143795669166667);
        case 253: return(3.1491633255833333);
        case 254: return(3.1511118609999995);
        default: return(0);
      }
    case 1: // Up
      switch(i) {
        case 50: return(0.6769205927666667);
        case 51: return(0.6941999991666666);
        case 52: return(0.7100823422166666);
        case 53: return(0.7186117569833333);
        case 54: return(0.7335382203166666);
        case 55: return(0.7535382509);
        case 56: return(0.7566264768333334);
        case 57: return(0.7694205939833334);
        case 58: return(0.7810382446);
        case 59: return(0.7928764720833333);
        case 60: return(0.8034647007666665);
        case 61: return(0.82000882425);
        case 62: return(0.8342000047166668);
        case 63: return(0.84206764895);
        case 64: return(0.8550823628666667);
        case 65: return(0.8764058749);
        case 66: return(0.8853029310833334);
        case 67: return(0.8916999896333332);
        case 68: return(0.9061852892166665);
        case 69: return(0.9208911657500001);
        case 70: return(0.9400823613166667);
        case 71: return(0.9436117808166666);
        case 72: return(0.9564794302166666);
        case 73: return(0.9676559368666667);
        case 74: return(0.9814794858);
        case 75: return(1.0008912284833333);
        case 76: return(1.0139059025000001);
        case 77: return(1.0205236076666668);
        case 78: return(1.028611839);
        case 79: return(1.0439794064999999);
        case 80: return(1.0644941525);
        case 81: return(1.0758176246666666);
        case 82: return(1.0886852741666666);
        case 83: return(1.0944206116666668);
        case 84: return(1.108244121);
        case 85: return(1.1240529616666668);
        case 86: return(1.1413323481666666);
        case 87: return(1.1539058685);
        case 88: return(1.1583175856666668);
        case 89: return(1.1675088208333333);
        case 90: return(1.1847147148333332);
        case 91: return(1.2044206063333334);
        case 92: return(1.2123617728333334);
        case 93: return(1.220302979);
        case 94: return(1.2300823925000002);
        case 95: return(1.2455235125);
        case 96: return(1.2598618069999998);
        case 97: return(1.2775823078333333);
        case 98: return(1.2861117525);
        case 99: return(1.3003764351666665);
        case 100: return(1.307655871);
        case 101: return(1.3259647291666667);
        case 102: return(1.3397882581666665);
        case 103: return(1.3485382796666665);
        case 104: return(1.3605235616666667);
        case 105: return(1.3736853199999999);
        case 106: return(1.3864794373333333);
        case 107: return(1.4057441551666667);
        case 108: return(1.4129500388333334);
        case 109: return(1.424273570666667);
        case 110: return(1.4353765051666667);
        case 111: return(1.4517735641666667);
        case 112: return(1.4653030038333335);
        case 113: return(1.4780235686666667);
        case 114: return(1.486626526);
        case 115: return(1.4996412198333333);
        case 116: return(1.5172882281666666);
        case 117: return(1.5271412333333332);
        case 118: return(1.5367735623333332);
        case 119: return(1.5575823785);
        case 120: return(1.5621411998333332);
        case 121: return(1.5740530093333334);
        case 122: return(1.5883176921666669);
        case 123: return(1.6005235711666668);
        case 124: return(1.6070677241666669);
        case 125: return(1.6271412571666666);
        case 126: return(1.636111776);
        case 127: return(1.6398618023333336);
        case 128: return(1.6436118285);
        case 129: return(1.6535382665);
        case 130: return(1.6640530029999996);
        case 131: return(1.6781706213333332);
        case 132: return(1.6957441370000002);
        case 133: return(1.7056706546666665);
        case 134: return(1.7153765161666668);
        case 135: return(1.7293471296666667);
        case 136: return(1.7378765741666669);
        case 137: return(1.7561117808333335);
        case 138: return(1.7717735768333334);
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

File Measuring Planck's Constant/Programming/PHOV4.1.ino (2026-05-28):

#include <math.h>
#include <phyphoxBle.h>

// Different for each box
const char* ssid = "phyphox:h (V4.1) ID/Kennung";

// Functions (without write_File, append_File)
void simon_says();
int reverse_cal_mapping(float);
int map_voltage_to_bit(int, int, int);
float current_mapping(int);
float cal_OUT_mapping(int, int);
float cal_IN_mapping(int);


// Pins
int pinOUT = 25;
int pinPOT = 4;
int pinRES = 2;

// phyphox vars
int mode;
int period; // 
float voltageTARGET; // V
float voltageLOW; // V
float voltageHIGH; // V

// General vars
float voltageOUT; // V
int bvoltageOUT;
float currentRES; // mA
float voltageRES; // V
int bvoltageRES;
float cal_factor;

// Vars for Mode 0 (manual)
int bvoltagePOT;
int bvoltageMIN;
int bvoltageMAX;

// Vars for Mode 2 (auto)
int bvoltageINC;
int cad; // ms
int bvoltageLOW;
int bvoltageHIGH;
int periodInUse;

uint8_t PLA[22025] = {80,75,3,4,20,0,0,0,8,0,29,125,113,92,41,33,162,5,214,37,0,0,248,154,0,0,26,0,0,0,50,
48,50,54,48,51,49,55,95,80,72,79,86,52,46,49,45,73,46,112,104,121,112,104,111,120,228,125,203,146,163,
72,154,238,126,204,230,29,52,177,202,42,117,166,0,9,93,218,178,210,12,16,8,132,36,4,232,134,218,170,211,
184,131,184,138,139,4,44,231,53,206,49,59,155,126,134,179,153,217,213,126,30,98,158,228,56,146,226,42,133,2,
69,100,117,87,207,201,50,171,144,28,252,243,255,238,255,239,238,160,175,161,149,135,86,144,213,118,122,20,219,129,
255,203,29,252,5,238,221,213,220,64,149,93,253,151,59,221,191,251,246,175,255,82,3,255,190,38,118,226,234,223,
166,174,236,171,78,141,8,252,56,145,253,164,246,201,15,106,170,236,233,145,252,211,215,198,241,150,211,253,170,156,
232,102,16,229,223,248,20,220,152,122,181,169,149,199,182,26,127,109,60,92,185,191,51,112,131,232,27,2,65,144,
44,131,171,135,111,167,75,154,30,171,145,29,38,128,180,111,99,93,142,211,72,143,107,137,165,215,118,129,155,200,
166,94,147,147,154,236,215,70,100,191,38,155,178,13,136,58,92,85,211,40,210,253,242,146,86,179,53,240,201,54,
236,83,199,196,2,16,86,224,106,15,16,129,113,184,0,48,190,212,22,71,49,212,90,95,224,47,95,27,79,71,
63,17,100,171,224,170,17,68,158,156,252,114,167,200,177,222,110,221,125,179,23,56,39,236,33,118,96,6,24,248,
55,17,231,22,57,55,193,167,113,249,191,62,67,96,18,248,75,36,75,182,173,131,15,2,1,185,36,191,16,90,
171,20,209,250,117,91,95,8,43,218,95,46,182,72,55,115,221,196,9,160,193,48,200,91,162,8,13,214,13,74,
74,109,110,177,94,59,252,210,82,130,84,236,51,33,193,22,88,68,68,44,41,110,84,133,24,195,60,11,199,3,
41,28,90,109,114,45,145,147,137,23,199,38,49,70,147,225,18,129,210,70,119,213,158,70,245,94,167,219,104,26,
134,161,162,13,20,45,162,102,179,57,77,186,171,108,211,233,26,59,77,175,183,208,102,115,92,239,245,10,95,215,
26,70,23,78,246,4,213,3,44,4,18,181,176,48,69,54,49,106,134,69,60,137,75,244,66,52,249,61,73,236,
119,172,137,153,34,57,153,99,212,222,18,76,124,239,207,54,202,120,16,152,24,62,152,219,246,96,41,75,152,201,
59,179,190,193,129,70,2,31,240,166,13,218,36,62,224,157,126,95,227,6,128,72,139,224,77,81,4,141,82,200,
147,125,66,227,184,216,20,45,140,199,100,81,102,164,117,8,176,64,227,36,222,203,54,134,145,107,145,101,214,160,
145,192,9,97,156,212,243,162,151,54,140,70,206,180,98,193,111,52,55,86,142,110,25,138,200,214,170,215,67,178,
62,134,98,118,3,78,114,136,157,54,119,43,13,129,8,69,202,101,122,168,136,51,130,138,136,77,143,71,148,97,
192,205,5,45,80,205,40,143,7,144,77,181,52,220,66,84,47,209,183,145,152,9,216,32,48,44,116,208,200,154,
245,212,37,218,238,110,63,25,213,195,17,79,207,214,154,181,227,53,187,179,150,66,9,165,164,237,30,34,13,174,
23,35,35,180,167,140,122,187,221,156,239,175,185,204,132,187,157,21,170,100,86,211,236,140,101,41,116,98,182,46,
101,45,79,20,134,205,133,180,200,70,35,35,136,179,110,29,177,186,178,71,133,24,178,159,70,41,190,37,109,121,
29,250,24,199,11,50,205,117,135,155,222,166,238,177,132,212,20,114,79,9,244,246,34,46,16,30,207,52,33,179,
155,204,20,155,33,41,161,161,208,108,92,120,168,162,168,248,216,22,52,114,218,243,29,102,178,155,113,107,107,178,
107,13,55,122,103,80,116,59,177,83,76,97,147,44,82,194,25,111,113,106,34,18,234,6,215,218,153,13,59,139,
57,63,236,143,103,249,84,104,214,179,206,124,230,164,118,104,17,189,137,235,206,227,150,203,76,56,44,99,219,67,
132,33,160,102,216,27,240,75,152,144,56,189,67,37,114,192,18,157,190,207,214,91,197,214,205,104,122,38,217,145,
197,249,45,63,25,165,27,16,89,162,141,47,65,97,86,151,121,92,192,141,182,149,88,6,103,204,151,64,57,132,
35,206,54,27,223,94,236,85,102,3,79,61,103,199,135,36,147,37,138,183,143,179,88,201,89,8,166,154,177,186,
242,27,155,78,212,159,192,24,212,103,231,100,220,81,240,81,177,72,26,209,6,37,153,38,180,182,71,45,223,93,
182,93,100,197,71,164,138,39,173,97,131,239,70,145,216,74,123,104,127,220,229,243,30,212,110,175,135,133,192,57,
22,173,14,122,56,57,234,165,68,62,92,244,186,88,91,236,208,117,30,29,18,179,20,106,19,84,95,78,28,122,
234,117,232,121,123,71,201,43,126,177,104,89,244,130,66,49,105,44,5,62,20,74,241,60,35,102,82,204,51,218,
104,104,202,123,202,153,219,154,50,86,87,203,5,29,246,33,154,192,155,59,155,239,11,152,211,163,242,216,200,252,
250,110,137,46,55,147,205,48,194,16,30,81,59,145,106,137,163,149,214,23,123,254,148,162,176,57,143,79,199,18,
222,15,188,57,43,46,48,78,92,238,71,46,7,33,1,177,166,248,86,15,26,20,104,200,37,106,187,167,102,58,
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

void setup() {
  Serial.begin(9600);
  while (!Serial) {delay(100);}
  
  // Enable Voltages
  pinMode(pinOUT, OUTPUT); // DAC output
  pinMode(pinPOT, INPUT); // Read voltage at potentiometer
  pinMode(pinRES, INPUT); // Read voltage at serial resistor


  // Set up bluetooth connection
  PhyphoxBLE::start(ssid, &PLA[0], sizeof(PLA)); // Start phyphox connection
  //PhyphoxBLE::setMTU(185); // Increase byte maximum
  PhyphoxBLE::configHandler=&simon_says; // Enable phyphox input

  // Set default values
  bvoltagePOT = 4095;
  bvoltageMIN = 50;
  bvoltageMAX = 254;
  bvoltageINC = 1;
  cad = 40;
  bvoltageOUT = bvoltageMIN + 10;
}
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

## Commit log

2026-05-12 Add files via upload
    Arduino Code for the phyphox:h box
2026-05-27 Update README.de.md
    Formulierung bei BB84 berichtigt.
2026-05-27 Update README.de.md
    Formatierung und Link zur englischen Readme hinzugefügt.
2026-05-27 Update README.de.md
    Formel ergänzt
2026-05-27 Add files via upload
    Handreichung und Auswertungsbogen zu BB84 hochgeladen
2026-05-27 Add files via upload
    Anleitungen für SuS und Studierende hochgeladen
2026-05-28 Add files via upload
    Hinzufügen der Experimente in Form einer ZIP-Datei zum Download
2026-05-28 Rename 2026_03_19_QC-Bundle_V4.1.zip to 00_2026_03_19_QC-Bundle_V4.1.zip
    Umbenennen des ZIP-files
2026-05-28 Rename Measuring Planck's Constant/Instructions/Anleitung Studierende.pdf to Measuring Planck's Constant/Instructions/de/Anleitung Studierende.pdf
2026-05-28 Rename Measuring Planck's Constant/Instructions/Anleitung SuS.pdf to Measuring Planck's Constant/Instructions/de/Anleitung SuS.pdf
2026-05-28 Rename Measuring Planck's Constant/Instructions/Handreichung Lehrkräfte.pdf to Measuring Planck's Constant/Instructions/de/Handreichung Lehrkräfte.pdf
2026-05-28 Rename BB84 Analogy/Instructions/Auswertungsbogen BB84.pdf to BB84 Analogy/Instructions/de/Auswertungsbogen BB84.pdf
2026-05-28 Rename BB84 Analogy/Instructions/Handreichung BB84.pdf to BB84 Analogy/Instructions/de/Handreichung BB84.pdf
2026-05-28 Rename Hocker Ledkasten v1.stl to Stabilisation_Aid_PBK.stl
    [Stabilisation_Aid_PBK.stl]
2026-05-28 Rename Test5.typ to Handreichung zur Fertigung des Aufbaus.typ
